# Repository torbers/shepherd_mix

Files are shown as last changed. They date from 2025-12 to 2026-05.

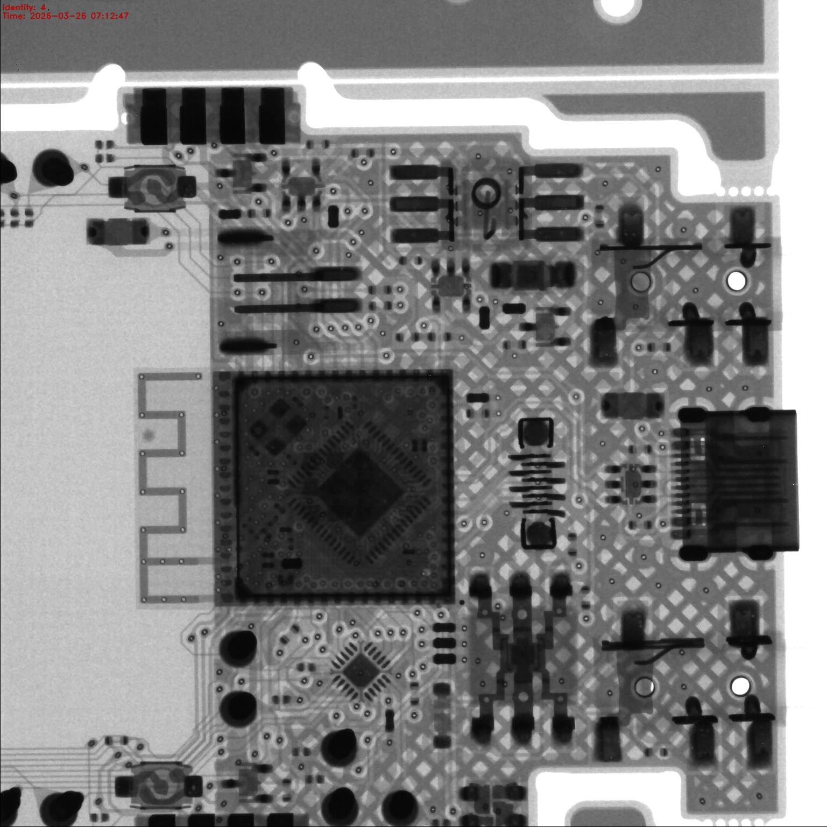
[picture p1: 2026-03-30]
brand/xray/4.jpg

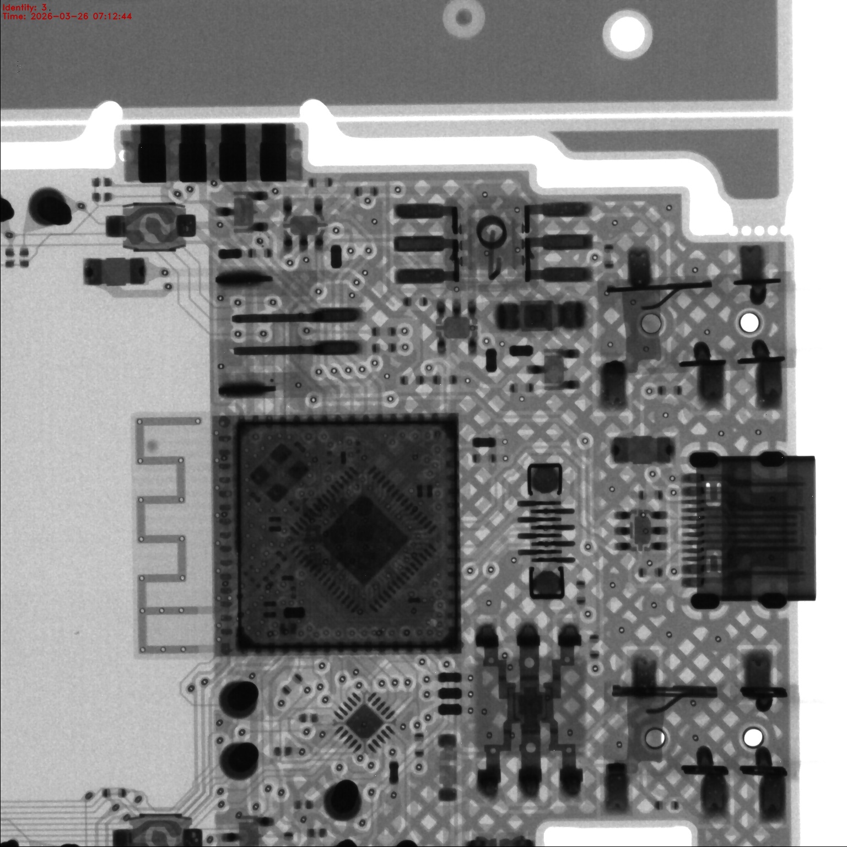
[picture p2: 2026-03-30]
brand/xray/3.jpg

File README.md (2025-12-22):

# shepherd_mix
modular music hardware system for everyone

---

License:

<a href="https://github.com/torbers/shepherd_mix">Shepherd Mix design specifications</a> © 2025 by <a href="http://sambkothe.com">Sam Kothe (torbers)</a> are licensed under <a href="https://creativecommons.org/licenses/by-sa/4.0/">CC BY-SA 4.0</a>

<a href="https://github.com/torbers/shepherd_mix">Shepherd Mix code</a> © 2025 by <a href="http://sambkothe.com">Sam Kothe (torbers)</a> is licensed under <a href="https://creativecommons.org/licenses/by-sa/4.0/">CC BY-SA 4.0</a>

<a href="https://github.com/torbers/shepherd_mix">Shepherd Mix PCB designs</a> © 2025 by <a href="http://sambkothe.com">Sam Kothe (torbers)</a> are licensed under <a href="https://creativecommons.org/licenses/by-nc-sa/4.0/">CC BY-NC-SA 4.0</a>

<a href="https://github.com/torbers/shepherd_mix">Shepherd Mix art</a> © 2025 by <a href="http://sambkothe.com">Sam Kothe (torbers)</a> is licensed under <a href="https://creativecommons.org/licenses/by-nc-sa/4.0/">CC BY-NC-SA 4.0</a>

This means that you may design, manufacture, and sell products compatible with Shepherd Mix or using its code in accordance with [open source standards](https://opensource.org/osd), but you may not sell my PCB source files, artistic designs, or products made with them. In any case, you must give [appropriate credit](https://creativecommons.org/licenses/by-sa/4.0/#ref-appropriate-credit).

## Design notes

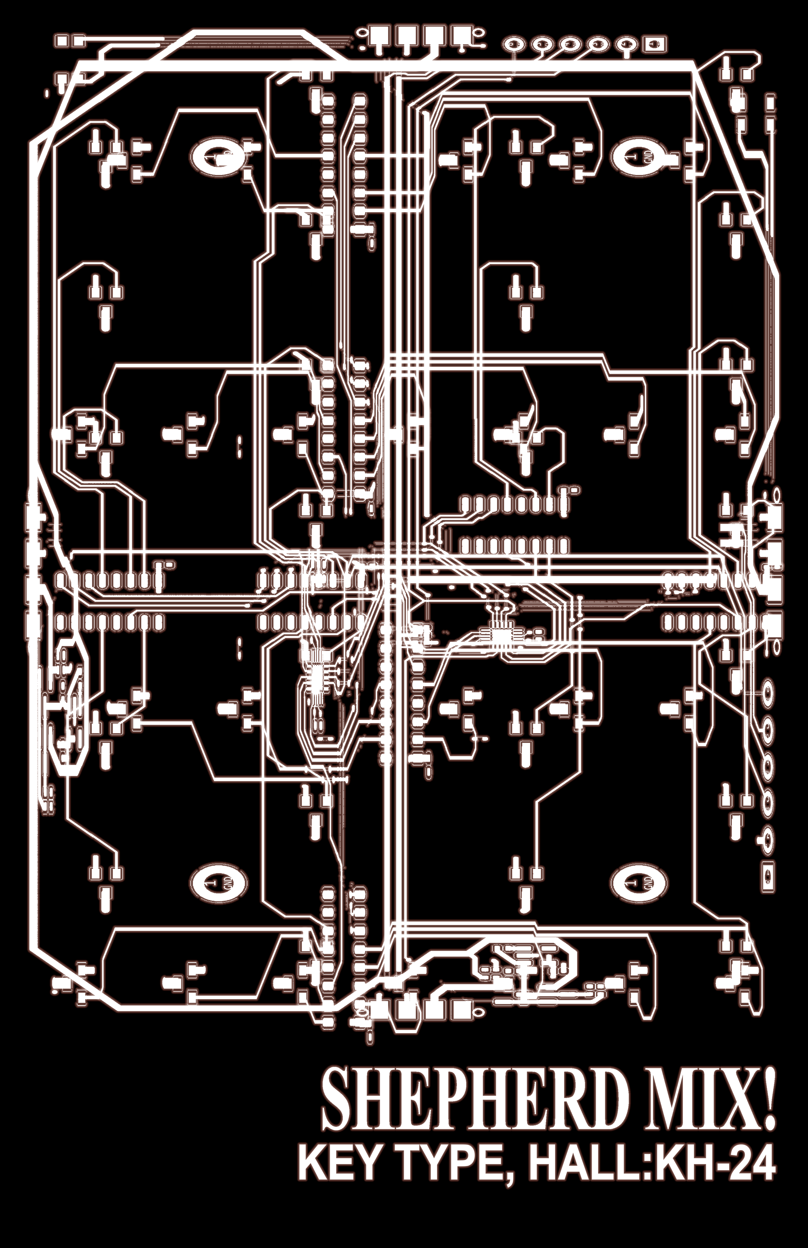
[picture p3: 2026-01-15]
brand/kh-24eva1117_v_both.png

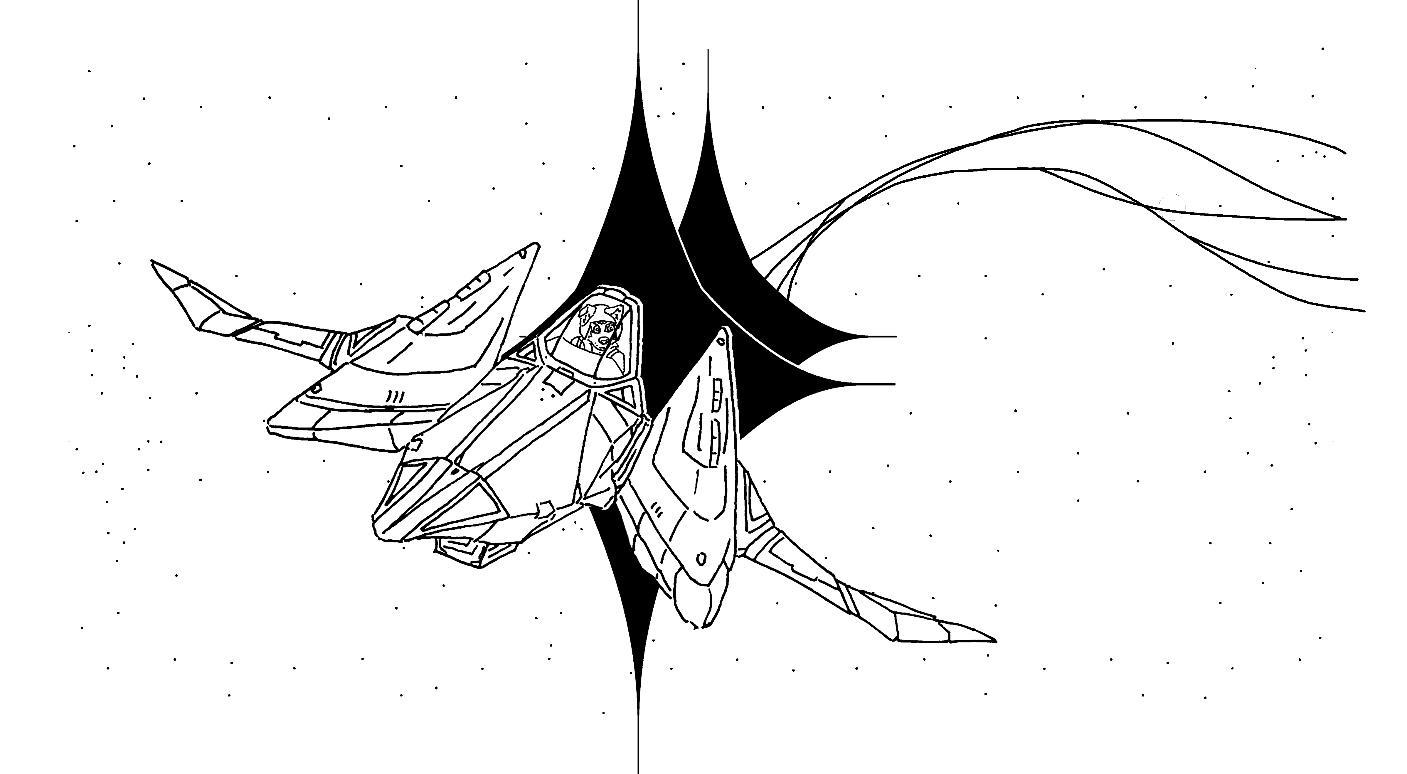
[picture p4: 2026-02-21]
kh-24 hall/hall_main_front3.png

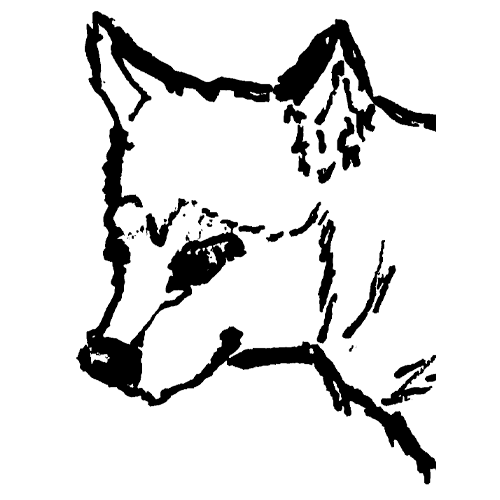
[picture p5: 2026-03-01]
kt-05 ctrl/dog1head.png

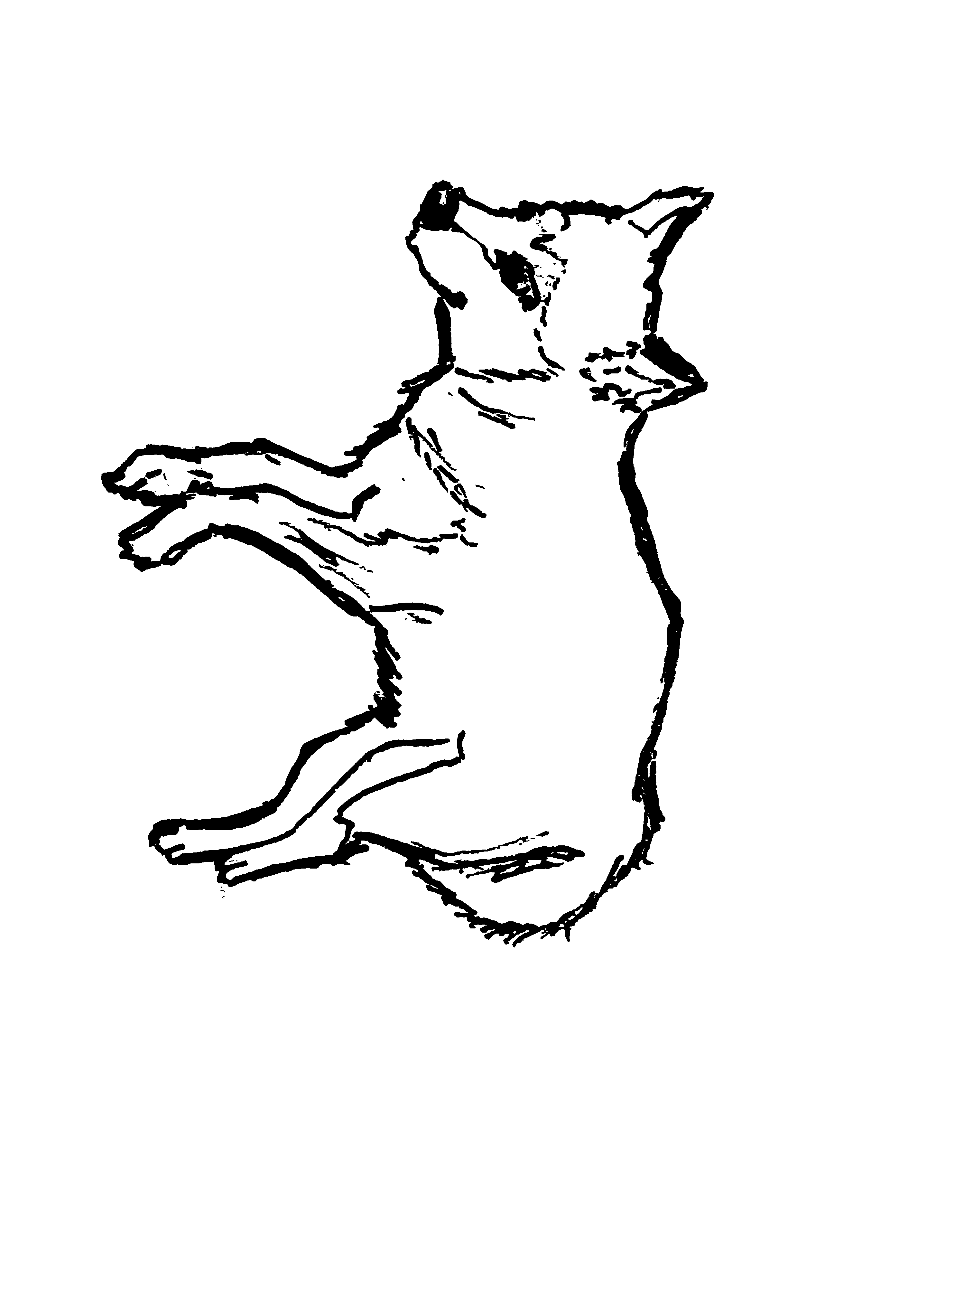
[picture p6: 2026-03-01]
kt-05 ctrl/dog1.png

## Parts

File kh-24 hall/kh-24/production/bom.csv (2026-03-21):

Designator | Footprint | Quantity | Value | LCSC Part #
C1, C2, C3, C4, C5 | 0402 | 5 | 0.1u
C6, C7, C8 | 0402 | 3 | 1u
CN3 | CONN-SMD_YZ199315035T-04025-01 | 1 | Pogo Pin Receptor Right | C5296825
KEY1, KEY10, KEY11, KEY12, KEY13, KEY14, KEY15, KEY16, KEY17, KEY18, KEY19, KEY2, KEY20, KEY21, KEY22, KEY23, KEY24, KEY3, KEY4, KEY5, KEY6, KEY7, KEY8, KEY9 | hall_key_footprint | 24 | 28115181DM | C47121944
LED2 | LED-SMD_4P-L3.2-W2.8_SK6812MINI-EA | 1 | SK6812MINI-EA | C5378731
Q1, Q3 | SOT-23 | 2 | AO3401A
R1, R2, R3, R4, R5, R6, R7, R8, R9 | 0402 | 9 | 10K
U1, U10, U12, U13, U14, U15, U16, U17, U19, U20, U21, U24, U25, U27, U28, U29, U30, U31, U32, U33, U35, U4, U6, U9 | SLSS49E_Hall_Switch_MX | 24 | SLSS49E-3 | C2904393
U11, U5 | DFN1006-2L-BI | 2 | H3V3U10B | C20615782
U18, U26, U3, U34 | SOIC-16_L9.9-W3.9-P1.27-LS6.0-BL | 4 | CD4051BM96 | C21379
U2 | VQFN-20-1EP_3x3mm_P0.4mm_EP1.7x1.7mm | 1 | ATtiny1616-M
U22 | SOT-583-8_L2.1-W1.2-P0.50-LS1.6-BL | 1 | LM66200DRLR | C3235556
U7 | CONN-SMD_4P-L11.0-W5.5-P2.50_YZ165615055F-04025-01 | 1 | Pogo Pin Left | C5296819
U8 | SOT-23-5 | 1 | AP2112K-3.3

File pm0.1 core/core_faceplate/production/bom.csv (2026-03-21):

Designator | Footprint | Quantity | Value | LCSC Part #
CN1, CN15, CN16, CN17, CN18, CN19, CN2, CN20, CN21, CN22, CN4 | SMD-1_BD2.0-H10.0 | 11 | YTC1P-6030-01 | C5221285

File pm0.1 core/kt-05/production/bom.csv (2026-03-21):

Designator | Footprint | Quantity | Value | LCSC Part #
C1, C2, C4, C8, C9 | 0402 | 5 | 10u
C3 | 0402 | 1 | 0.1u
C5, C6, C7 | 0402 | 3 | 1u
CN10, CN11, CN12, CN13, CN14, CN3, CN5, CN6, CN7, CN8, CN9 | SMD-1_BD2.0-H10.0 | 11 | YTC1P-6030-01 | C5221285
CN15 | AUDIO-SMD_PJ-327A5JJ | 1 | MIDI IN | C668605
CN16 | AUDIO-SMD_PJ-327A5JJ | 1 | MIDI OUT | C668605
CN4 | CONN-SMD_YZ199315035T-04025-01 | 1 | Pogo Pin Receptor Right | C5296825
D1 | SOT-23-6_L2.9-W1.6-P0.95-LS2.8-BL | 1 | USBLC6-2SC6 | C7519
D2 | SMA_L4.3-W2.6-LS5.2-RD | 1 | SS34_C8678 | C8678
D3 | D_SOD-123 | 1 | 1N4148W
F1, F2 | F1206 | 2 | BSMD1206-200-6V | C883134
FPC1 | FPC-SMD_8P-P0.50_HDGC_0.5K-A-8PB | 1 | 0.5K-A-8PB | C2914134
H2 | CONN-SMD_2P-P2.00_XUNPU_WAFER-PH2.0-2PWB | 1 | WAFER-PH2.0-2PWB | C3029440
Q1, Q2, Q3 | SOT-23 | 3 | AO3401A
R1, R20, R3 | 0402 | 3 | 5.1k
R10, R11, R2, R24, R4, R6, R7, R8, R9 | 0402 | 9 | 10K
R21, R22, R23 | 0402 | 3 | 100K
R25 | 0402 | 1 | 1M
R26 | 0402 | 1 | 10
R27 | 0402 | 1 | 33
R28, R29 | 0402 | 2 | 470
R5 | 0402 | 1 | 22R
SW1 | SW-SMD_L3.9-W3.0-P4.45 | 1 | ESP RST | C720477
SW2 | SW-SMD_L3.9-W3.0-P4.45 | 1 | ESP BOOT | C720477
U1 | LED-SMD_4P-L3.5-W3.5-BR_SK6812MINI-HS | 1 | SK6812MINI-HS | C2922787
U10, U11, U12, U13, U14, U15, U16, U17, U18, U19, U20, U21, U22, U23, U7 | DFN1006-2L-BI | 15 | H3V3U10B | C20615782
U2 | SOT-23-5 | 1 | AP2112K-3.3
U3 | SOT-23-5 | 1 | MCP73831-2-OT
U4 | SW-SMD_6P-L5.8-W5.8-P2.00-LS11.3 | 1 | PS-5850SVB-6PL | C5155567
U5 | SMD-6_L7.3-W6.5-P2.54-LS10.2-BL | 1 | H11L1S(TA) | C78589
U6 | VQFN-20-1EP_3x3mm_P0.4mm_EP1.7x1.7mm | 1 | ATtiny1616-M
U8 | ESP32-S2-MINI-1 | 1 | ESP32-S3-MINI-1
U9 | CONN-SMD_4P-L11.0-W5.5-P2.50_YZ165615055F-04025-01 | 1 | Pogo Pin Left | C5296819
USBC1 | USB-C_SMD-TYPE-C-31-M-12_1 | 1 | TYPE-C-31-M-12 | C165948

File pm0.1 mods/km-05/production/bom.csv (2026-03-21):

Designator | Footprint | Quantity | Value | LCSC Part #
C1 | 0402 | 1 | 0.1u
C6, C7 | 0402 | 2 | 10u
C8 | 0402 | 1 | 1u
CN1, CN10, CN11, CN12, CN14, CN2, CN4, CN5, CN6, CN7, CN8, CN9 | SMD-1_BD2.0-H10.0 | 12 | YTC1P-6030-01 | C5221285
CN3 | CONN-SMD_YZ199315035T-04025-01 | 1 | Pogo Pin Receptor Right | C5296825
Q3, Q4 | SOT-23 | 2 | AO3401A
R1, R2, R29, R3, R4 | 0402 | 5 | 10K
R10, R11, R12, R13, R14, R15, R16, R17, R18, R19, R20, R9 | 0402 | 12 | 0R
U1, U19, U20, U21, U22, U23, U24, U25 | LED-SMD_4P-L3.5-W3.5-BR_SK6812MINI-HS | 8 | SK6812MINI-HS | C2922787
U10, U11, U12, U13, U14, U15, U16, U17, U18, U3, U4, U5, U6, U9 | DFN1006-2L-BI | 14 | H3V3U10B | C20615782
U2 | VQFN-20-1EP_3x3mm_P0.4mm_EP1.7x1.7mm | 1 | ATtiny1616-M
U26 | SOT-583-8_L2.1-W1.2-P0.50-LS1.6-BL | 1 | LM66200DRLR | C3235556
U7 | CONN-SMD_4P-L11.0-W5.5-P2.50_YZ165615055F-04025-01 | 1 | Pogo Pin Left | C5296819
U8 | SOT-23-5 | 1 | AP2112K-3.3

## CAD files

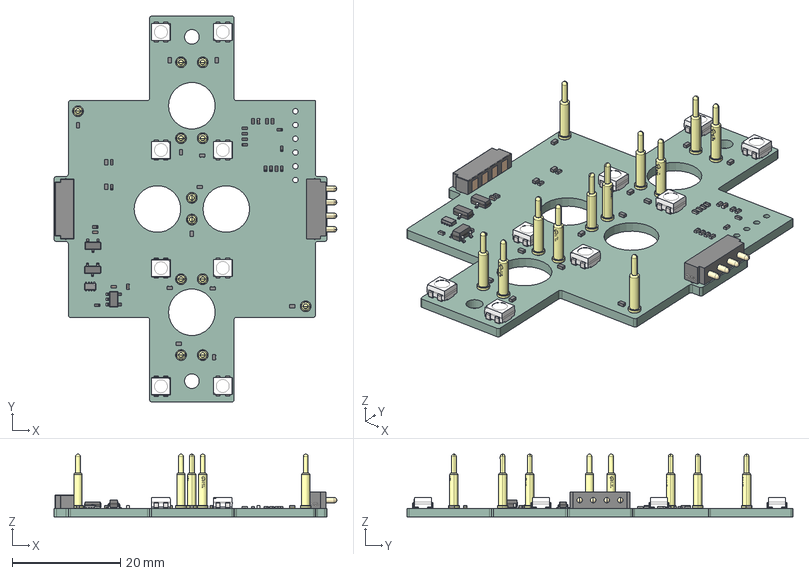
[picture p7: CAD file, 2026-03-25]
3d/complex/mods.step
52.1 x 71.2 x 11.6 mm
SMD-1_BD2.0-H10.0 x 12
R_0402_1005Metric x 17
LED-SMD_4P-L3.5-W3.5-BR_SK6812MINI-HS x 8
DFN1006-2L-BI x 14
SOT-23 x 2
CONN-SMD_YZ199315035T-04025-01
SOT-583-8_L2.1-W1.2-P0.50-LS1.6-BL
SOT-23-5
CONN-SMD_4P-L11.0-W5.5-P2.50_YZ165615055F-04025-01
C_0402_1005Metric x 4
km-05_PCB

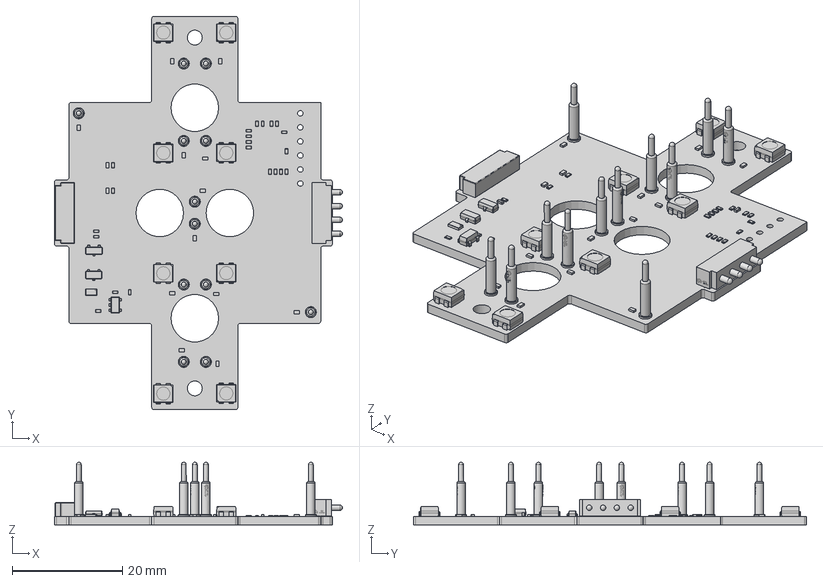
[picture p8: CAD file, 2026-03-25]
3d/MODS.step
52.1 x 71.2 x 11.3 mm

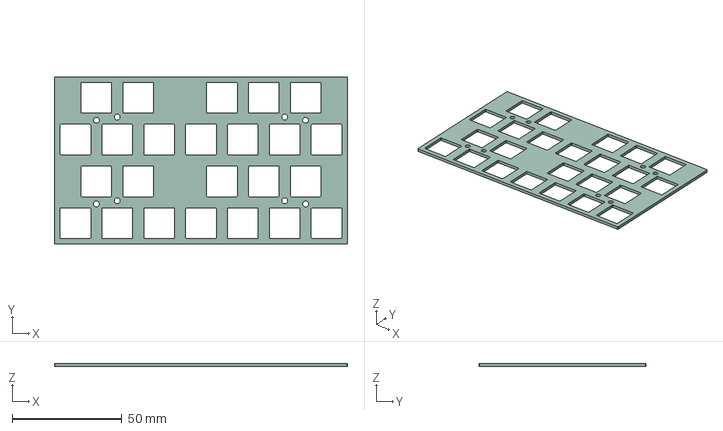
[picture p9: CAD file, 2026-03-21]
kh-24 hall/hall face/hall face.step
133.3 x 76.2 x 1.51 mm

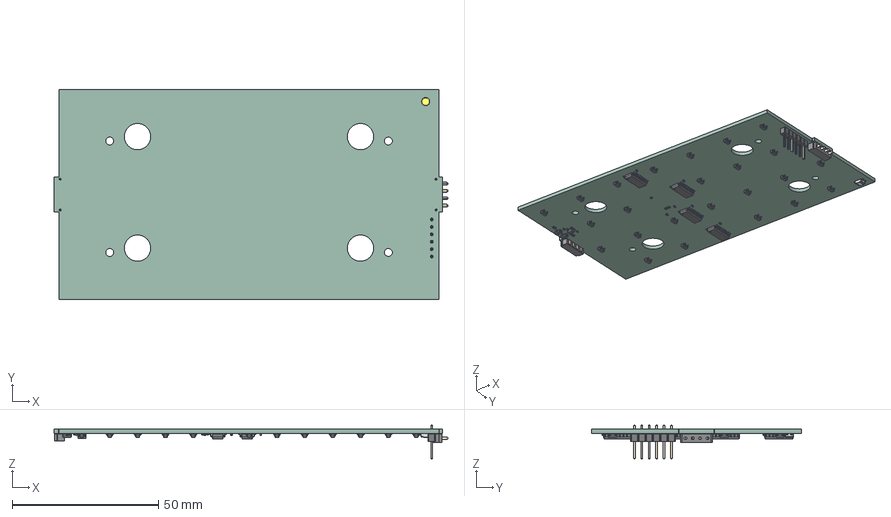
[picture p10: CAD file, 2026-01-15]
kh-24 hall/kh-24/kh-24.step
134.7 x 71.8 x 11.5 mm
C_0402_1005Metric x 7
SOT-23-3 x 24
SOIC-16_3.9x9.9mm_P1.27mm x 4
CONN-SMD_4P-L11.0-W5.5-P2.50_YZ165615055F-04025-01
SOT-23 x 2
R_0402_1005Metric x 8
DFN1006-2L-BI x 2
CONN-SMD_YZ199315035T-04025-01
PinHeader_1x06_P2.54mm_Vertical
LED-SMD_4P-L3.2-W2.8_SK6812MINI-EA
SOT-23-5
kh-24_PCB

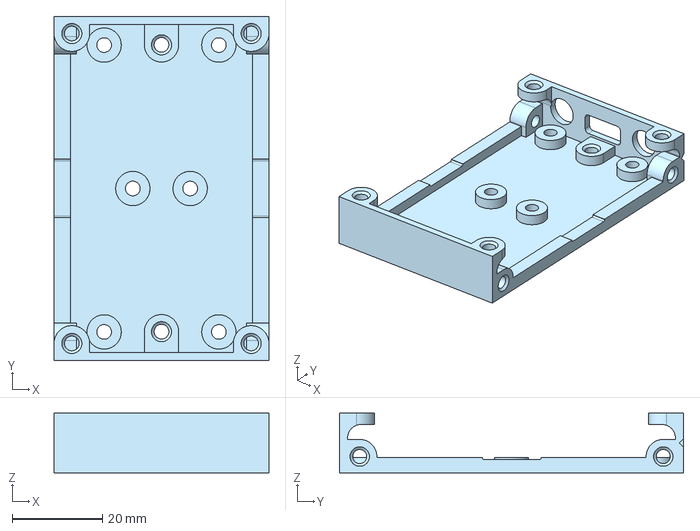
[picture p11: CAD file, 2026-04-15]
pm0.1 core/core - case.step
47.6 x 76.2 x 13.2 mm

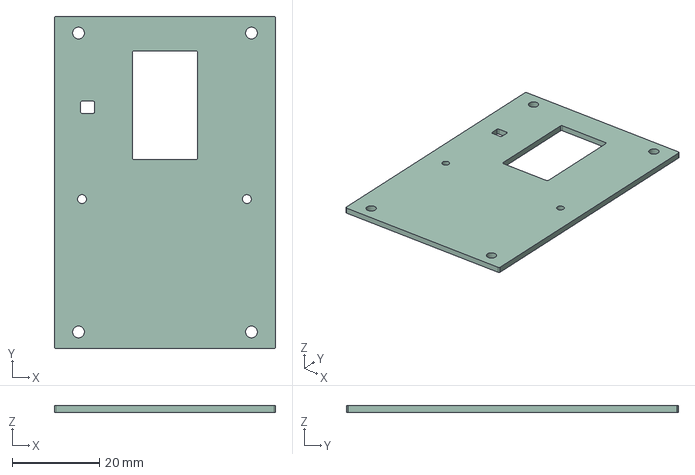
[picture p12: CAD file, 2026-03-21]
pm0.1 core/core_faceplate/core_faceplate.step
50.8 x 76.2 x 1.51 mm

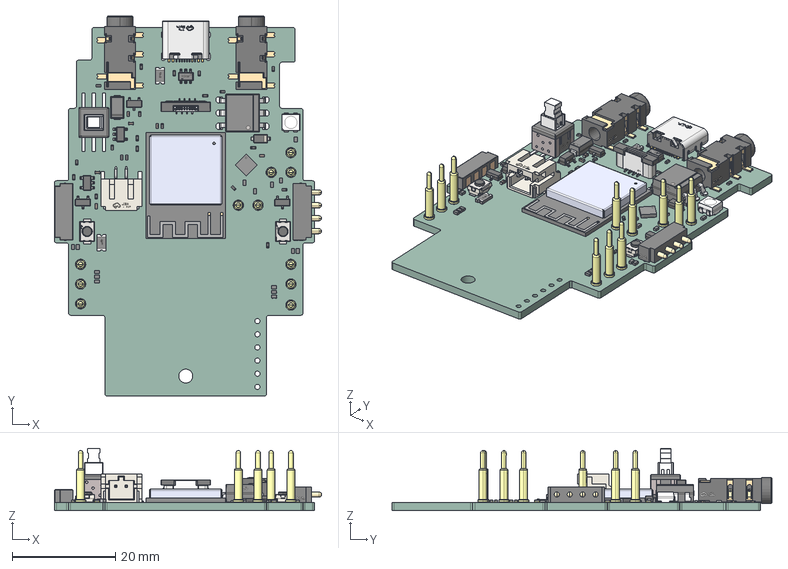
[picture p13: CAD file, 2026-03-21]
pm0.1 core/kt-05/kt-05.step
51.7 x 73.4 x 12.0 mm
R_0402_1005Metric x 21
FPC-SMD_8P-P0.50_HDGC_0.5K-A-8PB
F1206_L3.2-W1.7-H0.6 x 2
DFN1006-2L-BI x 15
SMD-1_BD2.0-H10.0 x 11
CONN-SMD_4P-L11.0-W5.5-P2.50_YZ165615055F-04025-01
C_0402_1005Metric x 6
LED-SMD_4P-L3.5-W3.5-BR_SK6812MINI-HS
CONN-SMD_2P-P2.00_XUNPU_WAFER-PH2.0-2PWB
SW-SMD_L3.9-W2.9-H2.0-LS4.8 x 2
SOT-23 x 3
USB-C_SMD-TYPE-C-31-M-12_1
SOT-23-6_L2.9-W1.6-H1.5-LS2.8-P0.95
AUDIO-SMD_PJ-327A5JJ x 2
QFN-20_L3.0-W3.0-P0.40-BL-EP1.7
ESP32-S2-MINI-1
SOT-23-5 x 2
D_SOD-123
SMA_L4.3-W2.6-LS5.2-RD
SW-SMD_6P-L5.8-W5.8-P2.00-LS11.3
SMD-6_L7.3-W6.5-H3.6-LS10.16-P2.54
CONN-SMD_YZ199315035T-04025-01
kt-05_PCB

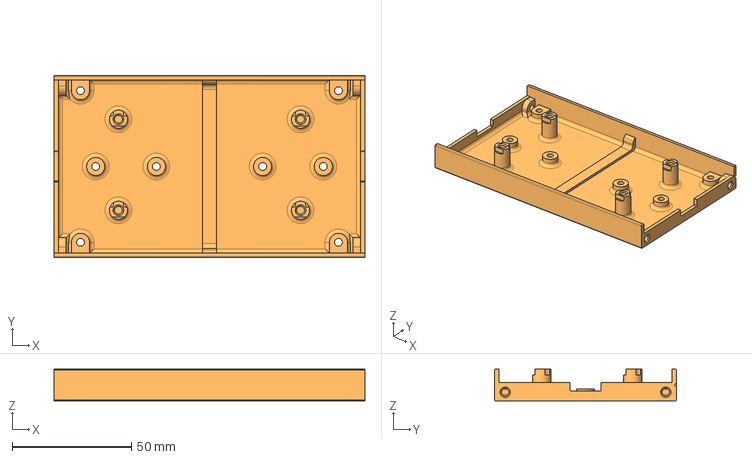
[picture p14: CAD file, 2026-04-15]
pm0.1 hall/hall - case.step
130.2 x 76.2 x 13.2 mm

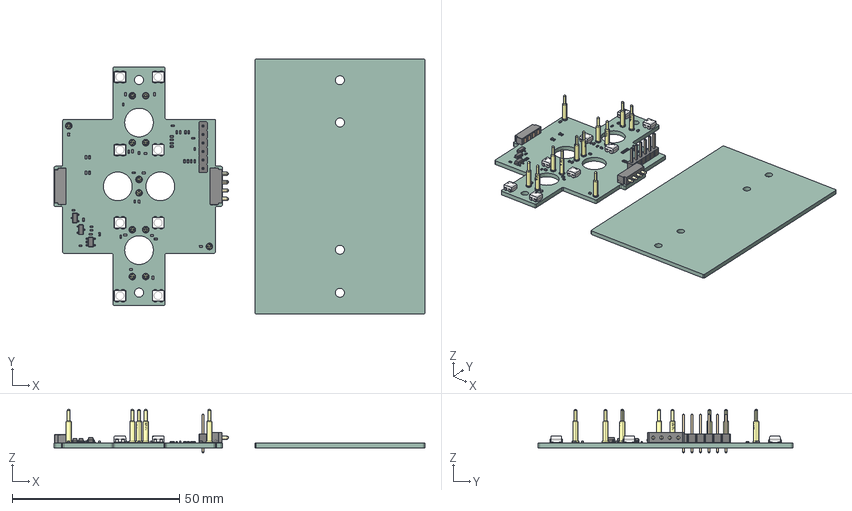
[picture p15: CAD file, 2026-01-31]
pm0.1 mods/km-05/km-05.step
110.8 x 76.2 x 13.0 mm
SMD-1_BD2.0-H10.0 x 12
SOT-23 x 2
LED-SMD_4P-L3.5-W3.5-BR_SK6812MINI-HS x 8
DFN1006-2L-BI x 14
R_0402_1005Metric x 28
CONN-SMD_YZ199315035T-04025-01
SOT-23-5
CONN-SMD_4P-L11.0-W5.5-P2.50_YZ165615055F-04025-01
PinHeader_1x06_P2.54mm_Vertical
C_0402_1005Metric x 3
km-05_PCB_1
km-05_PCB_2

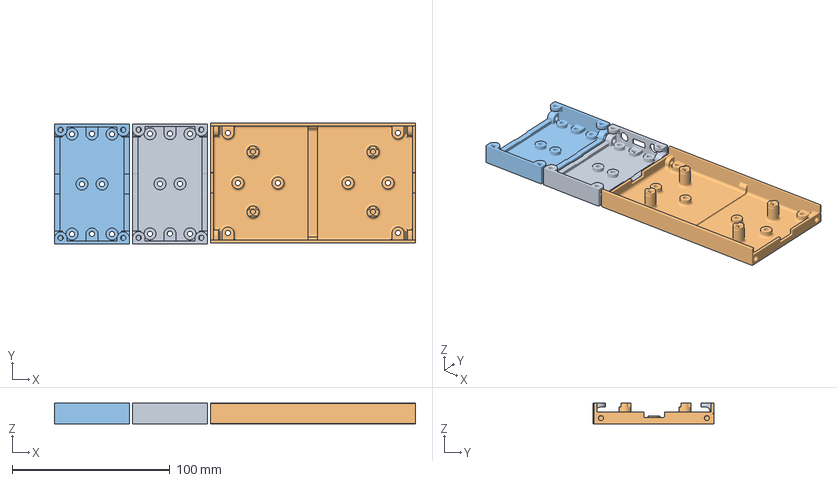
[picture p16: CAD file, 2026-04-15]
smix_all_xl.3mf
229.1 x 76.9 x 13.2 mm
core - case
hall - case
mods - case

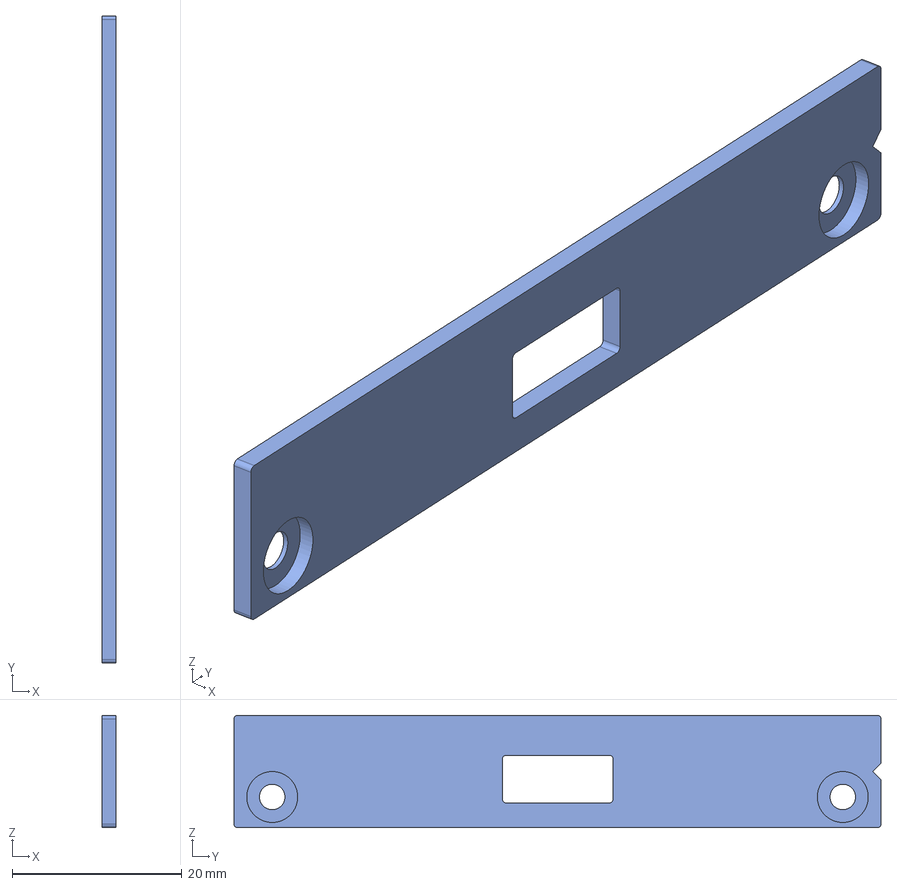
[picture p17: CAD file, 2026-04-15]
step/mods - mods_core_side_r.step
1.60 x 76.2 x 13.2 mm

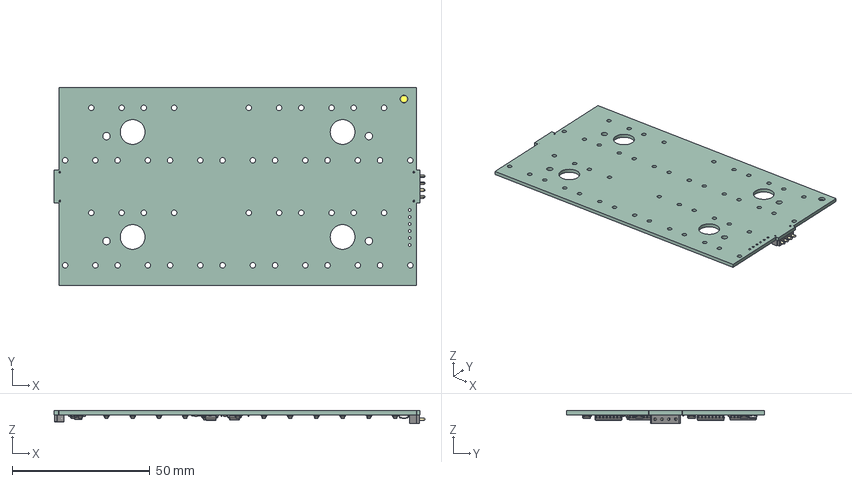
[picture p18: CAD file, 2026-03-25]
3d/complex/hall.step
134.7 x 71.8 x 4.60 mm
SOT-23 x 2
C_0402_1005Metric x 8
R_0402_1005Metric x 9
SOT-23-3 x 24
SOIC-16_3.9x9.9mm_P1.27mm x 2
CONN-SMD_4P-L11.0-W5.5-P2.50_YZ165615055F-04025-01
SOIC-16_L9.9-W3.9-H1.8-LS6.0-P1.27 x 2
DFN1006-2L-BI x 2
CONN-SMD_YZ199315035T-04025-01
SOT-583-8_L2.1-W1.2-P0.50-LS1.6-BL
LED-SMD_4P-L3.2-W2.8_SK6812MINI-EA
SOT-23-5
kh-24_PCB

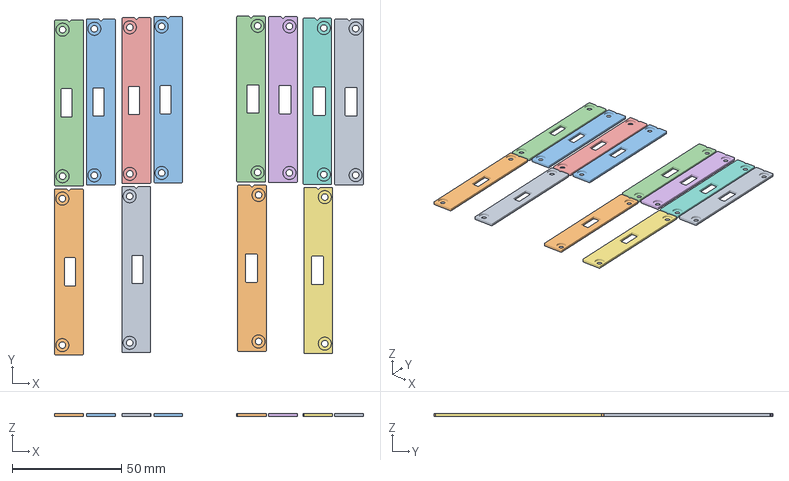
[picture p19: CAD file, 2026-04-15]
step/sides.3mf
141.7 x 155.4 x 1.60 mm
hall - hall_side_l x 2
hall - hall_side_r x 2
mods - mods_core_side_l x 4
mods - mods_core_side_r x 4

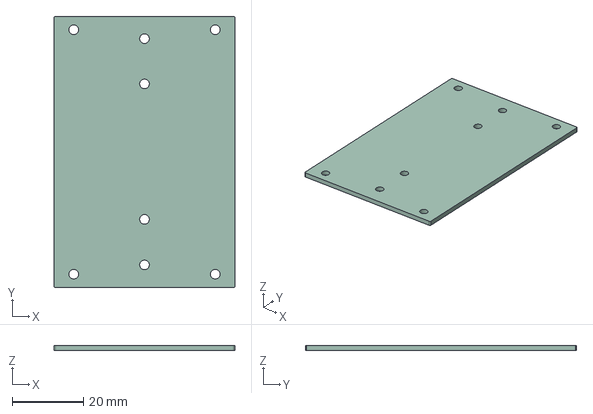
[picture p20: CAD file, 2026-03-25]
3d/mods_faceplate.step
50.8 x 76.2 x 1.51 mm

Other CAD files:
pm0.1 mods/mods - case.step
3d/HALL.step
3d/complex/core.step
step/mods - mods_core_side_l.step
3d/CORE.step
3d/core_faceplate.step
3d/hall_faceplate.step
kh-24 hall/hall face/hall face-F_Silkscreen.dxf
new_old/3d/CORE.step
new_old/3d/HALL.step
new_old/3d/complex/core.step
new_old/3d/core_faceplate.step
new_old/3d/hall_faceplate.step
new_old/kh-24 hall/hall face/hall face-F_Silkscreen.dxf
new_old/step/core - case.step
new_old/step/hall - case.step
new_old/step/hall - hall_side_l.step
new_old/step/hall - hall_side_r.step
new_old/step/mods - case.step
new_old/step/mods_core_side_l.step
new_old/step/mods_core_side_r.step
new_old/step/shep_rebuild.3mf
old/m2/mctl_p_v4 - face.dxf
old/m2/mctl_p_v4 - pcb.dxf
step/core - case.step
step/hall - case.step
step/hall - hall_side_l.step
step/hall - hall_side_r.step
step/mods - case.step
step/mods_core_side_l.step
step/mods_core_side_r.step

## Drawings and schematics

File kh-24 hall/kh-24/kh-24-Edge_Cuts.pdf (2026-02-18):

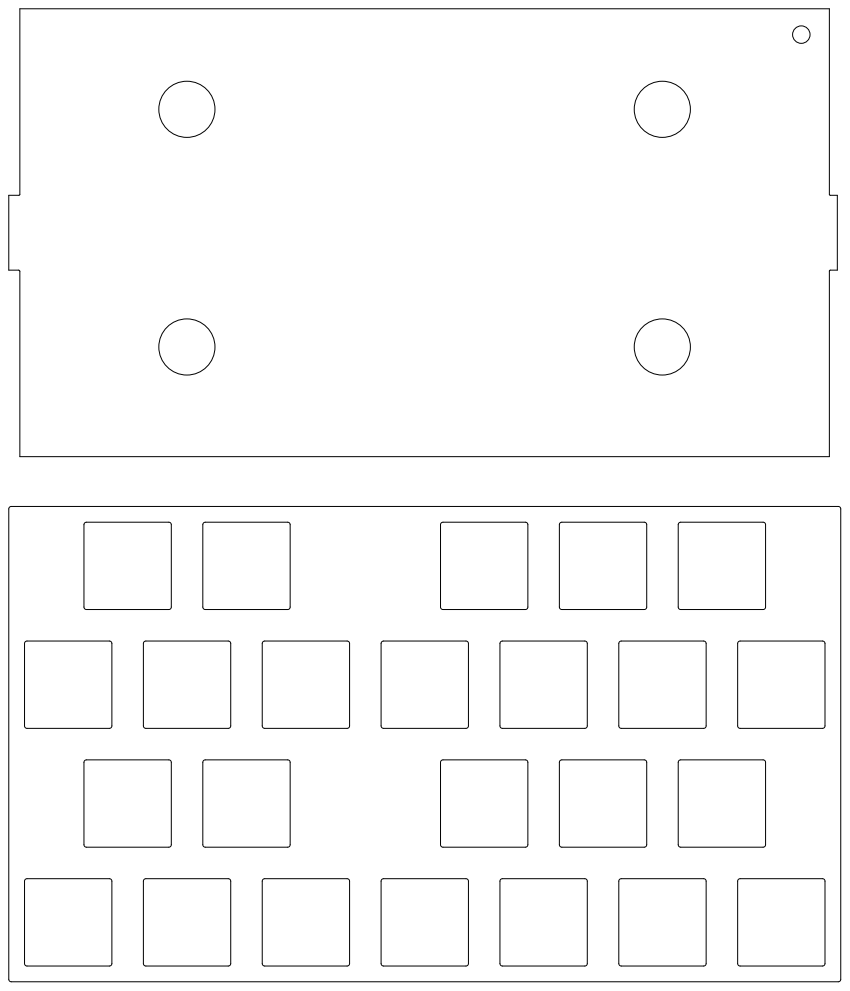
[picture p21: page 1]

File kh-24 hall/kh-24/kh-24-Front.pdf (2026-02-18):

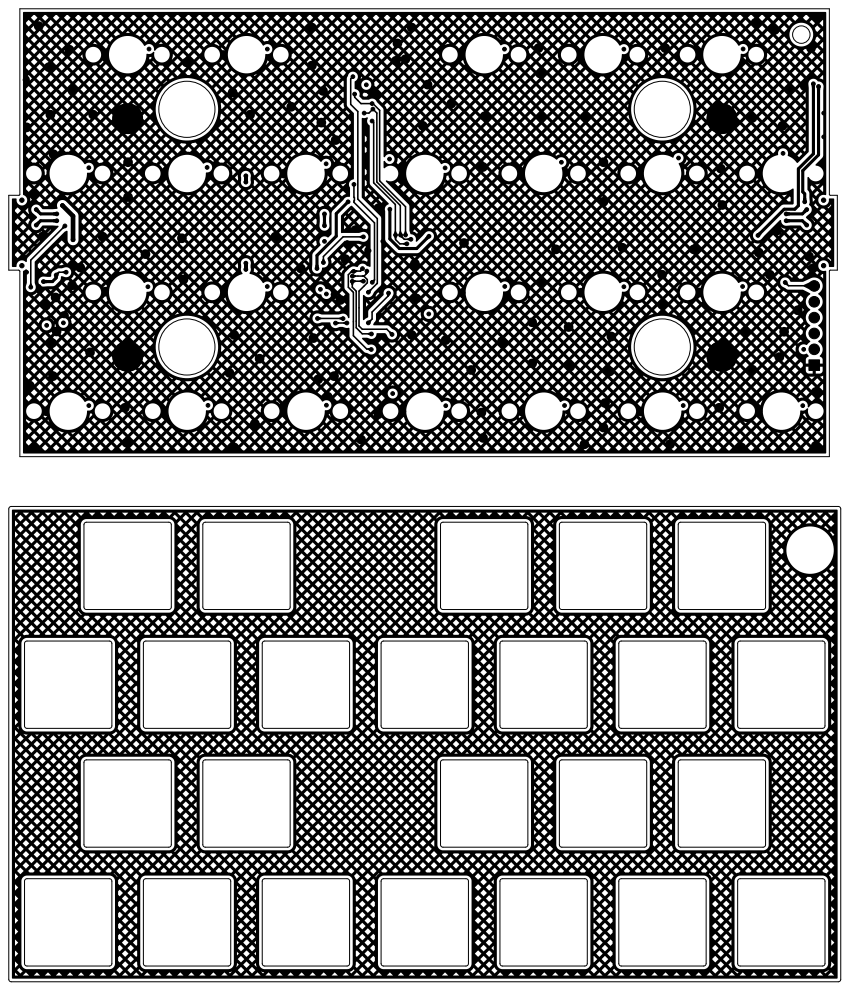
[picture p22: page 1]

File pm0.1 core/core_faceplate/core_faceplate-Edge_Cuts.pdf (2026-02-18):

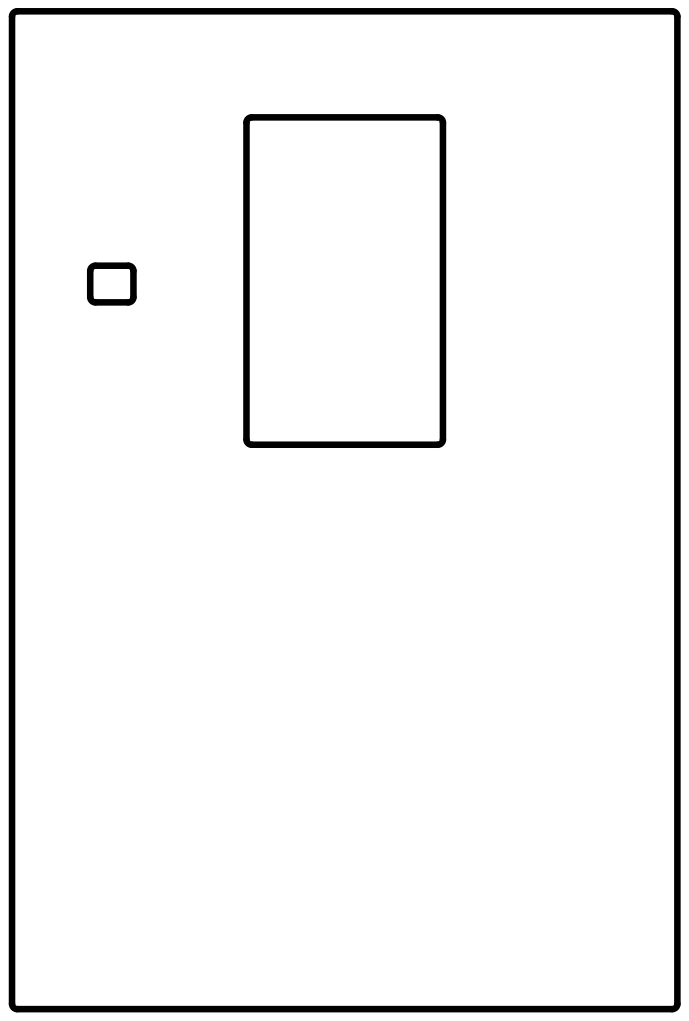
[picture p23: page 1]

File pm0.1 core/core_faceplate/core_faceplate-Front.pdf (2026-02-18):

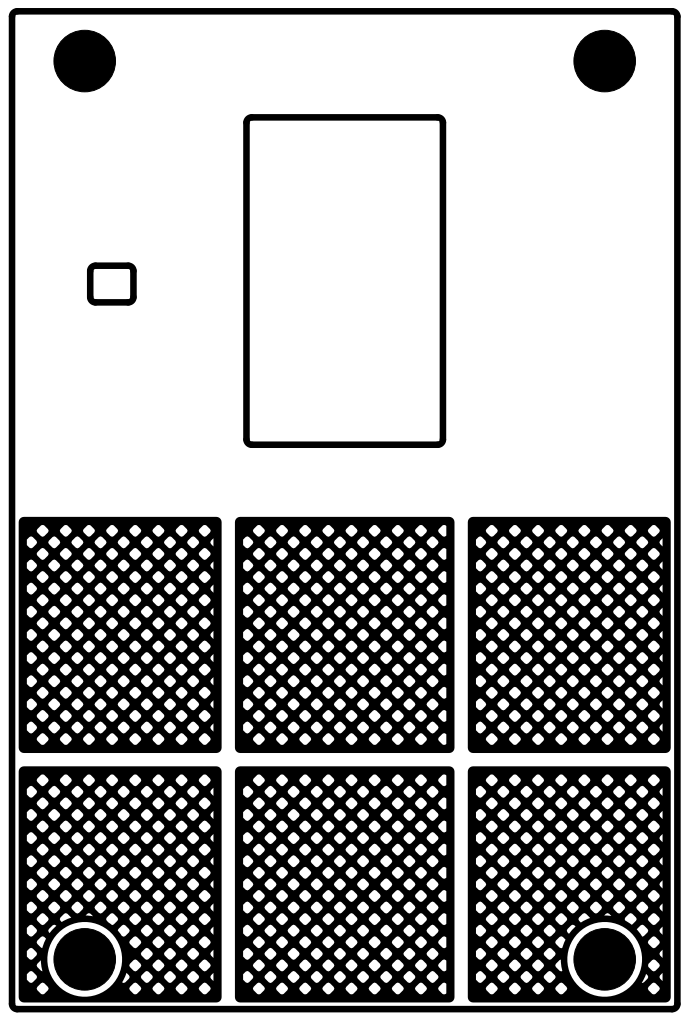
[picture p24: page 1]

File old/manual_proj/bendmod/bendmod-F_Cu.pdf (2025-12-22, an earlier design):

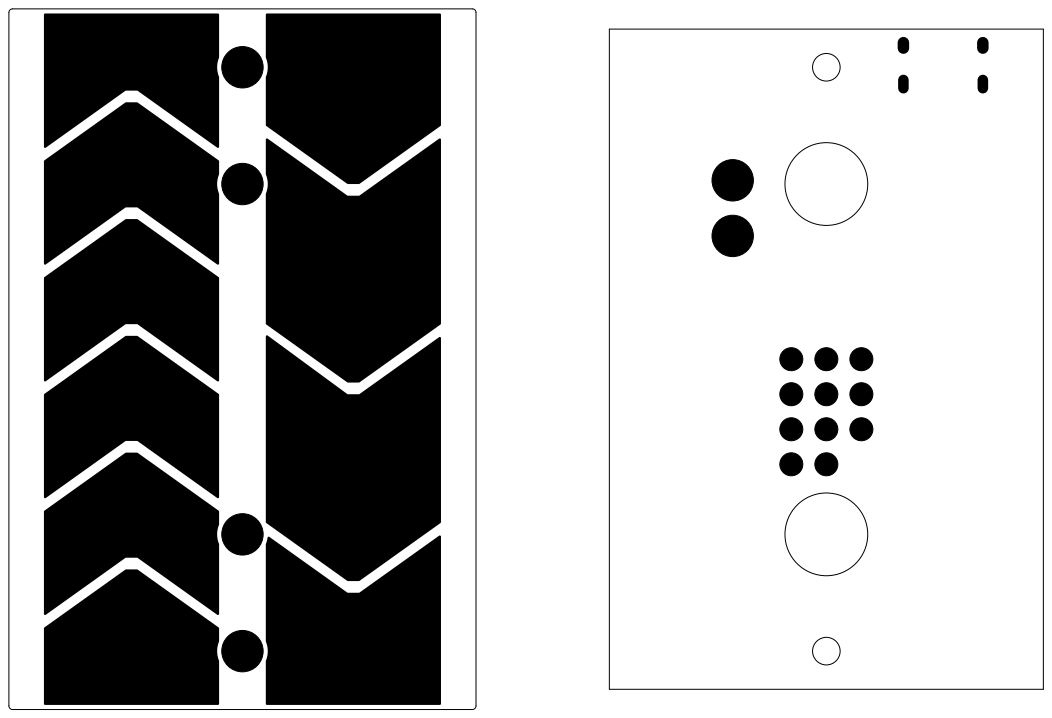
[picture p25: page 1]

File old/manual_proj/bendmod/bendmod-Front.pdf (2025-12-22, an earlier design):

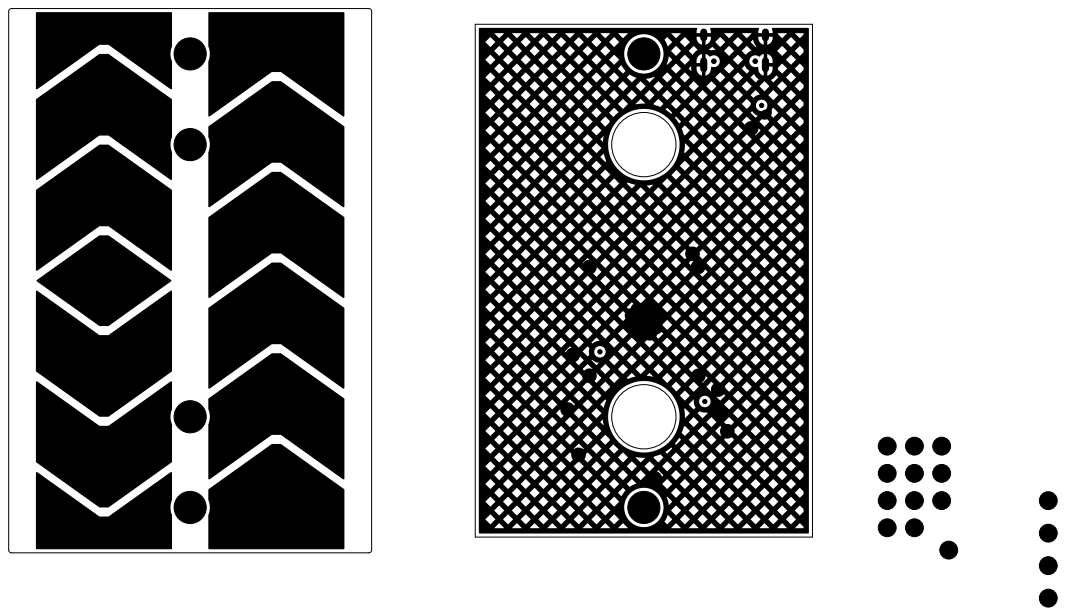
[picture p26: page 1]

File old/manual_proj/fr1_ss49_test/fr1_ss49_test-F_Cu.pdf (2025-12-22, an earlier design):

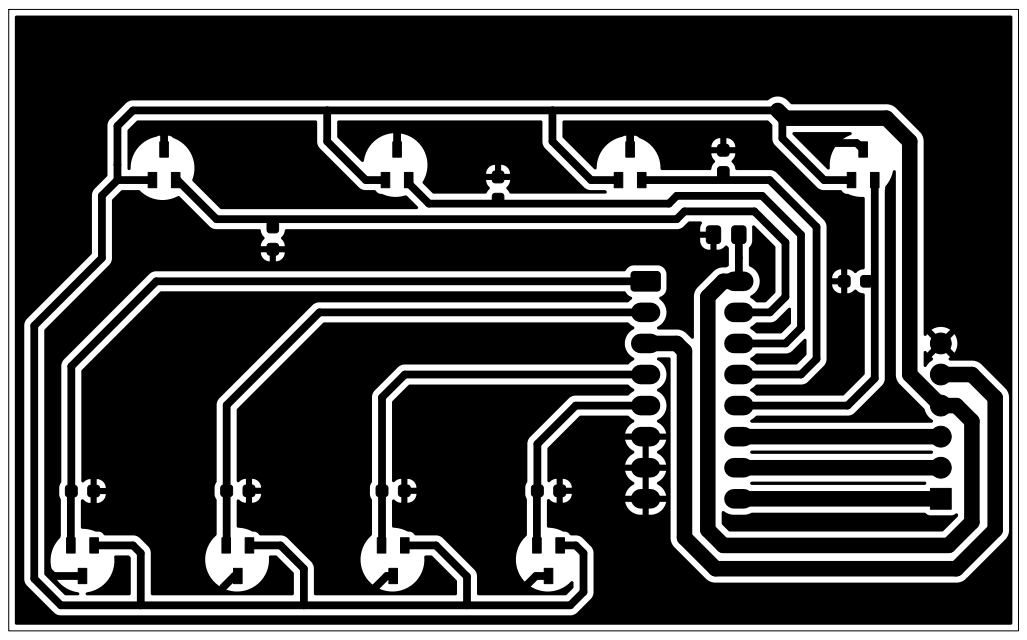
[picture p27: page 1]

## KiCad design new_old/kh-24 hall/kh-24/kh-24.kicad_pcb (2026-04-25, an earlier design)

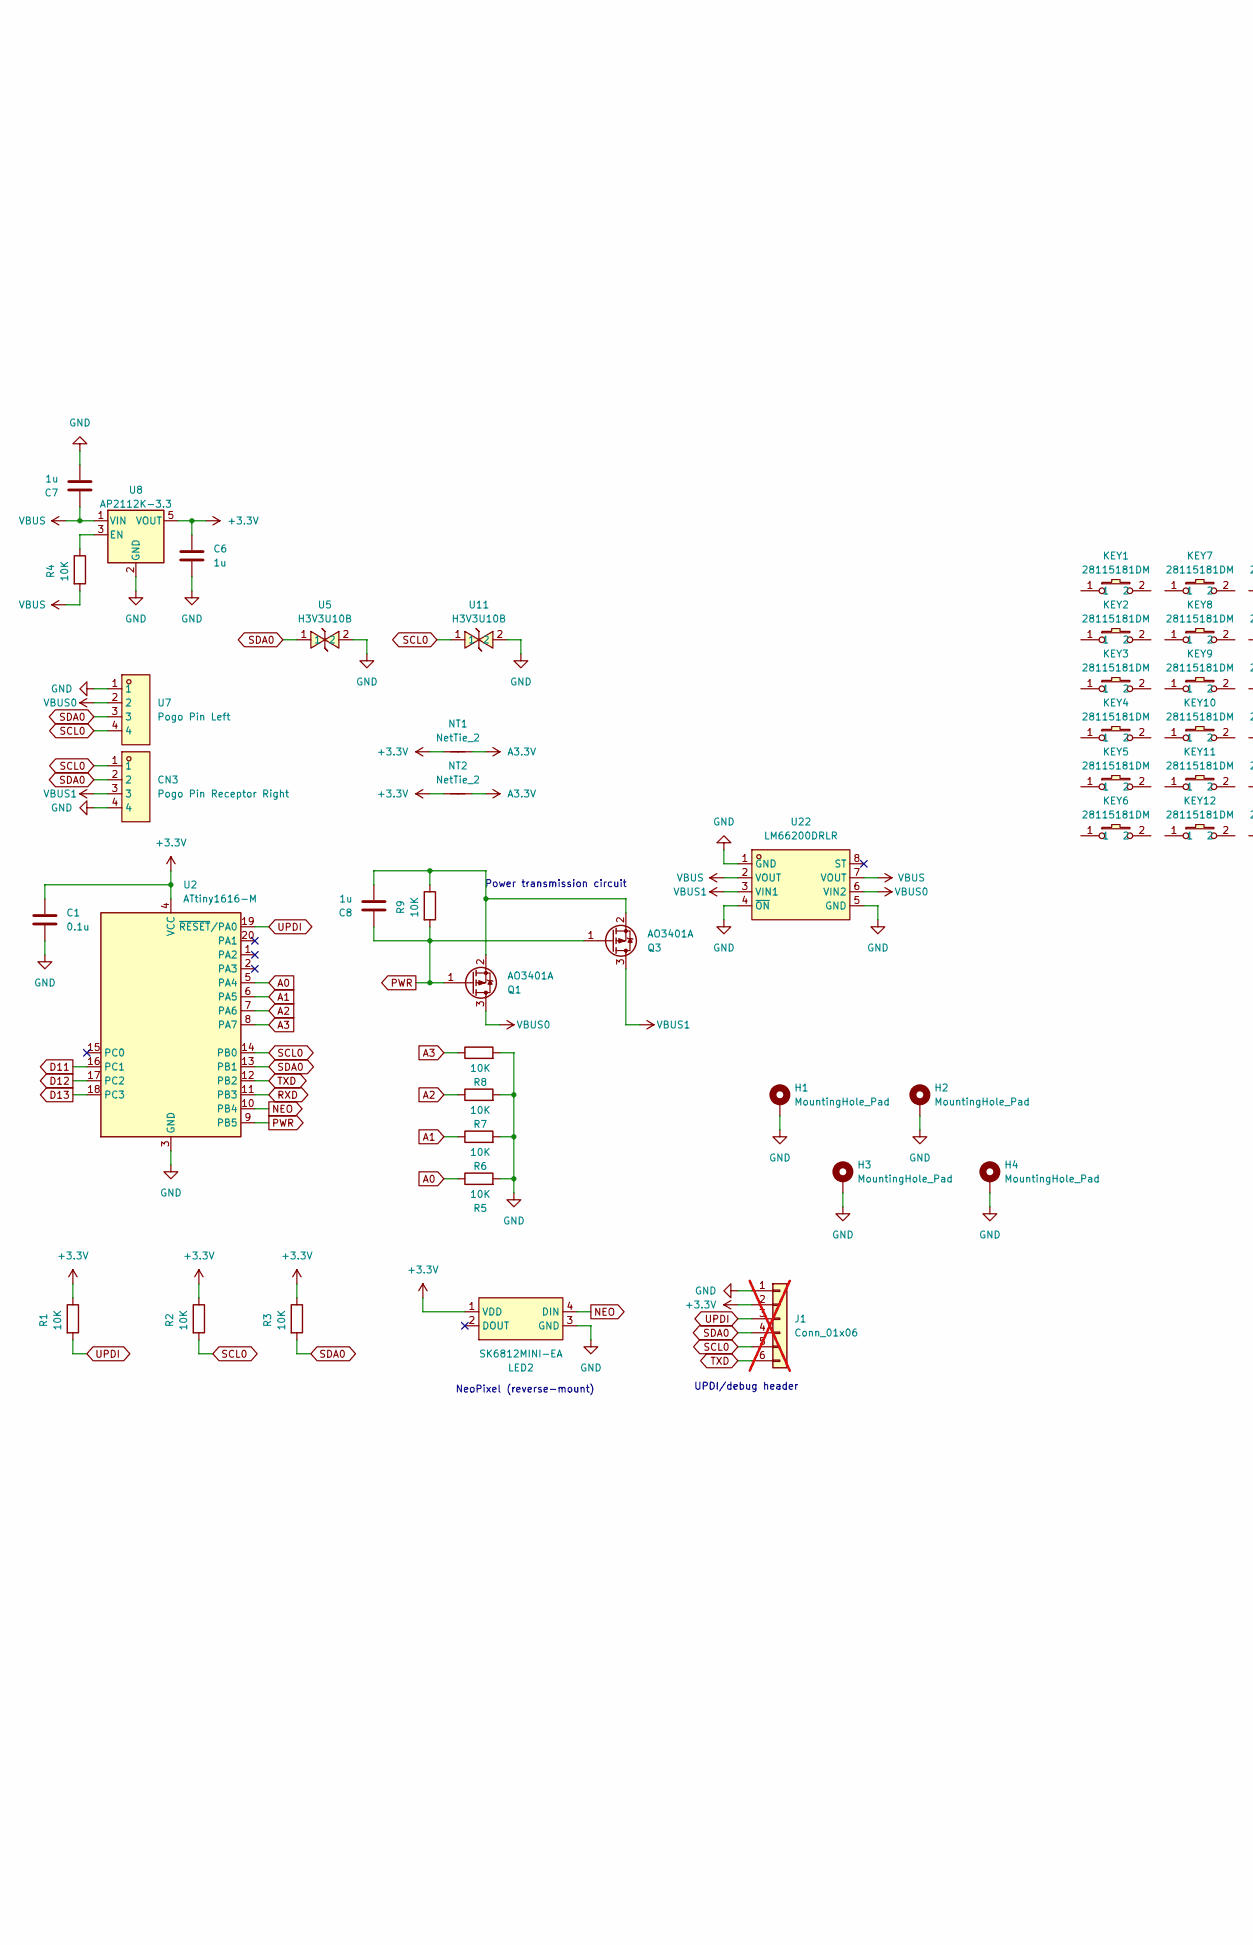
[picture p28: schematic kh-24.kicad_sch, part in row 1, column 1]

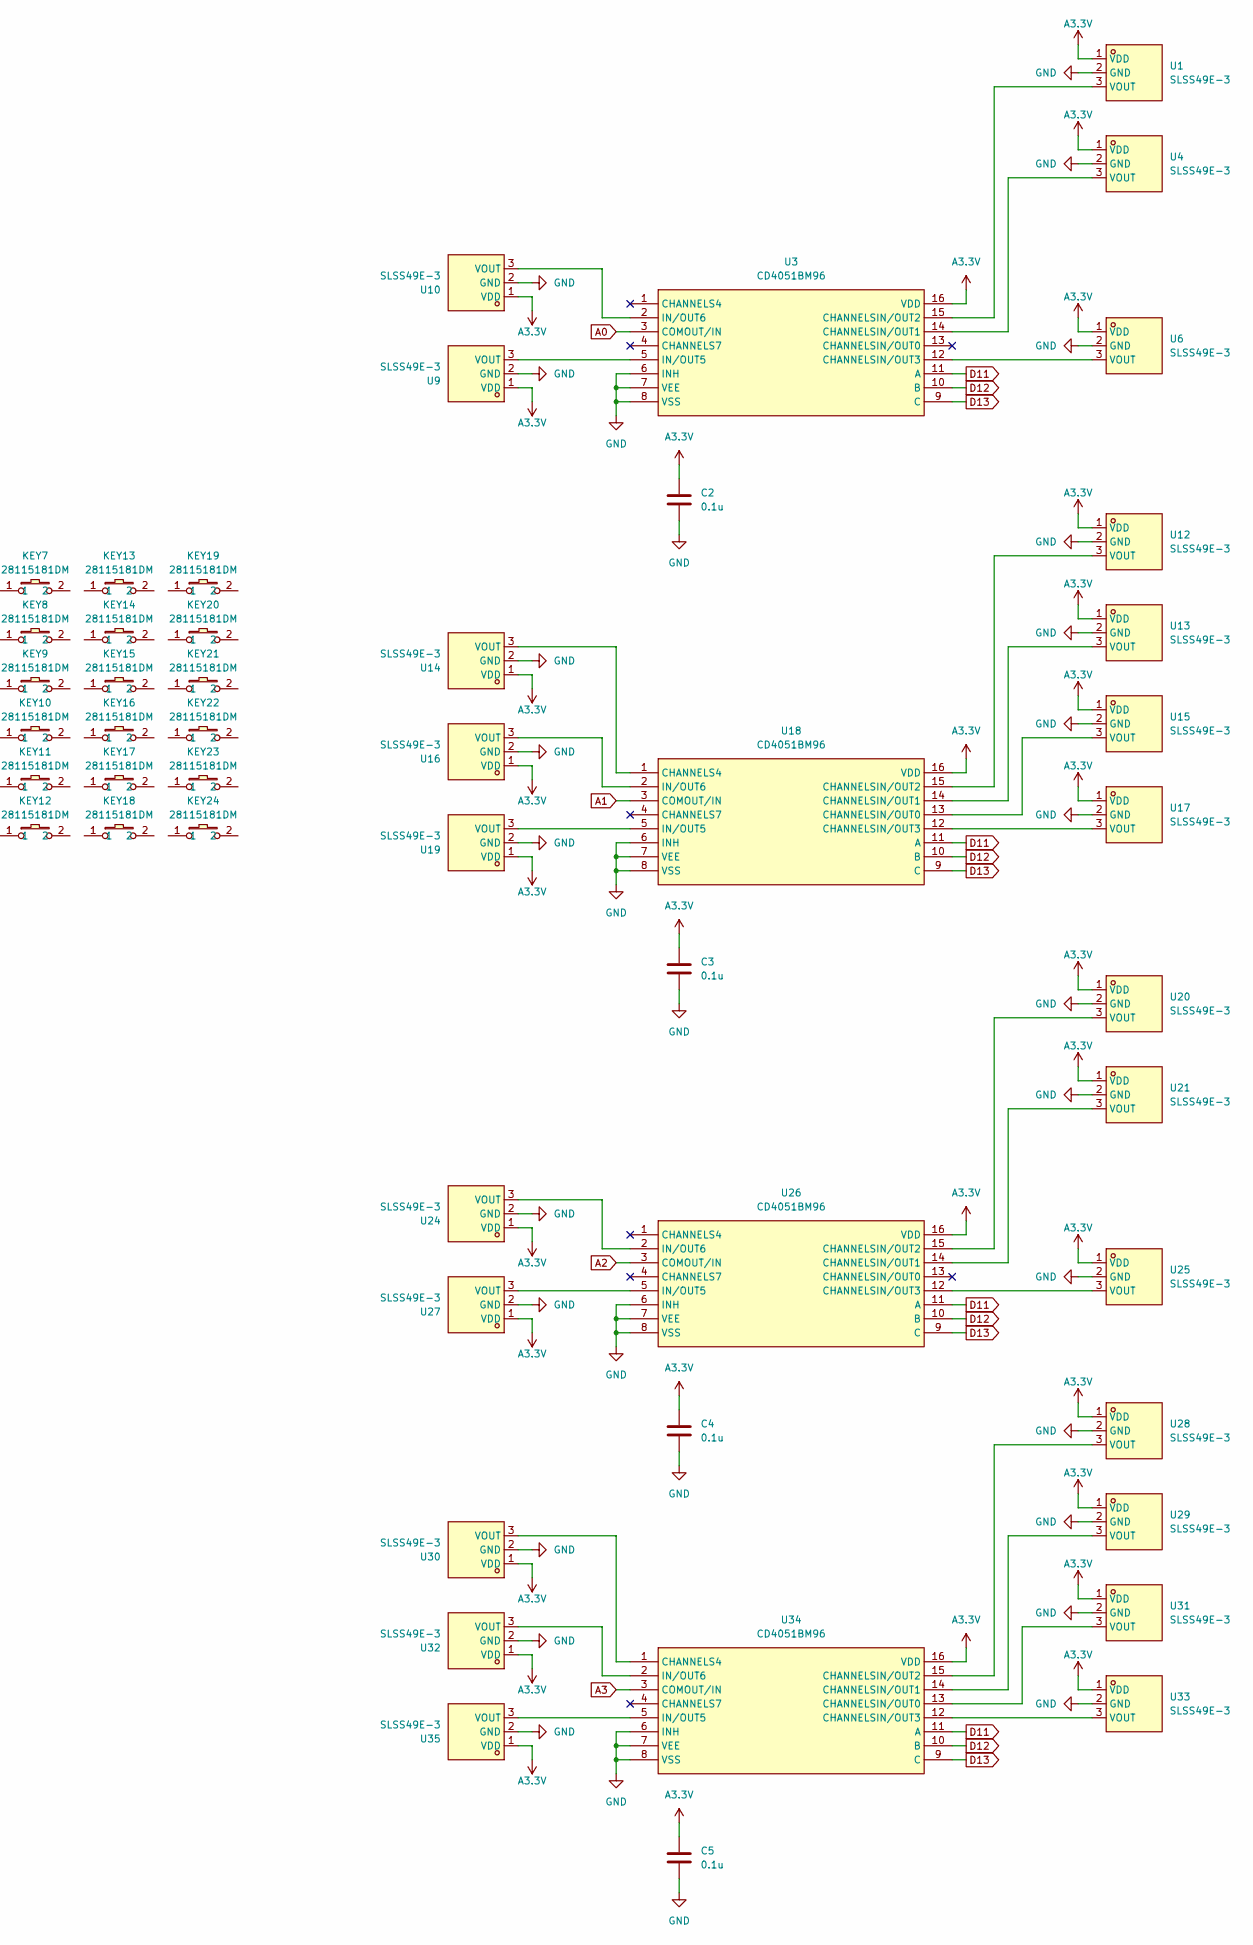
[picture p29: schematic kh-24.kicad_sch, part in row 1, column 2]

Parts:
C1, C2, C3, C4, C5: 0.1u; C_0402_1005Metric
C6, C7, C8: 1u; C_0402_1005Metric
CN3: Pogo Pin Receptor Right; CONN-SMD_YZ199315035T-04025-01; LCSC Part C5296825
H1, H2, H3, H4: MountingHole_Pad; MountingHole_2.7mm_M2.5_DIN965_Pad_TopBottom
J1: Conn_01x06; PinHeader_1x06_P2.54mm_Vertical; not fitted
KEY1, KEY2, KEY3, KEY4, KEY5, KEY6, KEY7, KEY8, KEY9, KEY10, KEY11, KEY12, KEY13, KEY14, KEY15, KEY16, KEY17, KEY18, KEY19, KEY20, KEY21, KEY22, KEY23, KEY24: 28115181DM; hall_key_footprint; LCSC Part C47121944
LED2: SK6812MINI-EA; LED-SMD_4P-L3.2-W2.8_SK6812MINI-EA; LCSC Part C5378731
NT1, NT2: NetTie_2; NetTie-2_SMD_Pad0.5mm
Q1, Q3: AO3401A; SOT-23
R1, R2, R3, R4, R9: 10K; R_0402_1005Metric
R5, R6, R7, R8: 10K; R_0402_1005Metric_Pad0.72x0.64mm_HandSolder
U1, U4, U6, U9, U10, U12, U13, U14, U15, U16, U17, U19, U20, U21, U24, U25, U27, U28, U29, U30, U31, U32, U33, U35: SLSS49E-3; SLSS49E_Hall_Switch_MX; LCSC Part C2904393
U2: ATtiny1616-M; VQFN-20-1EP_3x3mm_P0.4mm_EP1.7x1.7mm
U3, U18, U26, U34: CD4051BM96; SOIC-16_L9.9-W3.9-P1.27-LS6.0-BL; LCSC Part C21379
U5, U11: H3V3U10B; DFN1006-2L-BI; LCSC Part C20615782
U7: Pogo Pin Left; CONN-SMD_4P-L11.0-W5.5-P2.50_YZ165615055F-04025-01; LCSC Part C5296819
U8: AP2112K-3.3; SOT-23-5
U22: LM66200DRLR; SOT-583-8_L2.1-W1.2-P0.50-LS1.6-BL; LCSC Part C3235556

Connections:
+3.3V: C1.1, C6.1, J1.2, LED2.1 (VDD), NT1.1, NT2.1, R1.1, R2.1, R3.1, U2.4 (VCC), U8.5 (VOUT)
A0: R5.1, U2.5 (PA4), U3.3 (COMOUT/IN)
A1: R6.1, U2.6 (PA5), U18.3 (COMOUT/IN)
A2: R7.1, U2.7 (PA6), U26.3 (COMOUT/IN)
A3: R8.1, U2.8 (PA7), U34.3 (COMOUT/IN)
A3.3V: C2.1, C3.1, C4.1, C5.1, NT1.2, NT2.2, U1.1 (VDD), U3.16 (VDD), U4.1 (VDD), U6.1 (VDD), U9.1 (VDD), U10.1 (VDD), U12.1 (VDD), U13.1 (VDD), U14.1 (VDD), U15.1 (VDD), U16.1 (VDD), U17.1 (VDD), U18.16 (VDD), U19.1 (VDD), U20.1 (VDD), U21.1 (VDD), U24.1 (VDD), U25.1 (VDD), U26.16 (VDD), U27.1 (VDD), U28.1 (VDD), U29.1 (VDD), U30.1 (VDD), U31.1 (VDD), U32.1 (VDD), U33.1 (VDD), U34.16 (VDD), U35.1 (VDD)
D11: U2.16 (PC1), U3.11 (A), U18.11 (A), U26.11 (A), U34.11 (A)
D12: U2.17 (PC2), U3.10 (B), U18.10 (B), U26.10 (B), U34.10 (B)
D13: U2.18 (PC3), U3.9 (C), U18.9 (C), U26.9 (C), U34.9 (C)
GND: C1.2, C2.2, C3.2, C4.2, C5.2, C6.2, C7.2, CN3.4, H1.1, H2.1, H3.1, H4.1, J1.1, LED2.3 (GND), R5.2, R6.2, R7.2, R8.2, U1.2 (GND), U2.3 (GND), U2.21 (GND), U3.6 (INH), U3.7 (VEE), U3.8 (VSS), U4.2 (GND), U5.2, U6.2 (GND), U7.1, U8.2 (GND), U9.2 (GND), U10.2 (GND), U11.2, U12.2 (GND), U13.2 (GND), U14.2 (GND), U15.2 (GND), U16.2 (GND), U17.2 (GND), U18.6 (INH), U18.7 (VEE), U18.8 (VSS), U19.2 (GND), U20.2 (GND), U21.2 (GND), U22.1 (GND), U22.4 (~ON), U22.5 (GND), U24.2 (GND), U25.2 (GND), U26.6 (INH), U26.7 (VEE), U26.8 (VSS), U27.2 (GND), U28.2 (GND), U29.2 (GND), U30.2 (GND), U31.2 (GND), U32.2 (GND), U33.2 (GND), U34.6 (INH), U34.7 (VEE), U34.8 (VSS), U35.2 (GND)
NEO: LED2.4 (DIN), U2.10 (PB4)
unnamed: C8.2, Q1.2 (S), Q3.2 (S), R9.1
unnamed: U1.3 (VOUT), U3.15 (CHANNELSIN/OUT2)
unnamed: U3.14 (CHANNELSIN/OUT1), U4.3 (VOUT)
unnamed: U3.12 (CHANNELSIN/OUT3), U6.3 (VOUT)
unnamed: U3.5 (IN/OUT5), U9.3 (VOUT)
unnamed: R4.1, U8.3 (EN)
unnamed: U3.2 (IN/OUT6), U10.3 (VOUT)
unnamed: U12.3 (VOUT), U18.15 (CHANNELSIN/OUT2)
unnamed: U13.3 (VOUT), U18.14 (CHANNELSIN/OUT1)
unnamed: U14.3 (VOUT), U18.1 (CHANNELS4)
unnamed: U15.3 (VOUT), U18.13 (CHANNELSIN/OUT0)
unnamed: U16.3 (VOUT), U18.2 (IN/OUT6)
unnamed: U17.3 (VOUT), U18.12 (CHANNELSIN/OUT3)
unnamed: U18.5 (IN/OUT5), U19.3 (VOUT)
unnamed: U20.3 (VOUT), U26.15 (CHANNELSIN/OUT2)
unnamed: U21.3 (VOUT), U26.14 (CHANNELSIN/OUT1)
unnamed: U24.3 (VOUT), U26.2 (IN/OUT6)
unnamed: U25.3 (VOUT), U26.12 (CHANNELSIN/OUT3)
unnamed: U26.5 (IN/OUT5), U27.3 (VOUT)
unnamed: U28.3 (VOUT), U34.15 (CHANNELSIN/OUT2)
unnamed: U29.3 (VOUT), U34.14 (CHANNELSIN/OUT1)
unnamed: U30.3 (VOUT), U34.1 (CHANNELS4)
unnamed: U31.3 (VOUT), U34.13 (CHANNELSIN/OUT0)
unnamed: U32.3 (VOUT), U34.2 (IN/OUT6)
unnamed: U33.3 (VOUT), U34.12 (CHANNELSIN/OUT3)
unnamed: U34.5 (IN/OUT5), U35.3 (VOUT)
PWR: C8.1, Q1.1 (G), Q3.1 (G), R9.2, U2.9 (PB5)
RXD: U2.11 (PB3)
SCL0: CN3.1, J1.5, R2.2, U2.14 (PB0), U7.4, U11.1
SDA0: CN3.2, J1.4, R3.2, U2.13 (PB1), U5.1, U7.3
TXD: J1.6, U2.12 (PB2)
UPDI: J1.3, R1.2, U2.19 (~RESET/PA0)
VBUS: C7.1, R4.2, U8.1 (VIN), U22.2 (VOUT), U22.7 (VOUT)
VBUS0: Q1.3 (D), U7.2, U22.6 (VIN2)
VBUS1: CN3.3, Q3.3 (D), U22.3 (VIN1)

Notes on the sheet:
Power transmission circuit
NeoPixel (reverse-mount)
UPDI/debug header

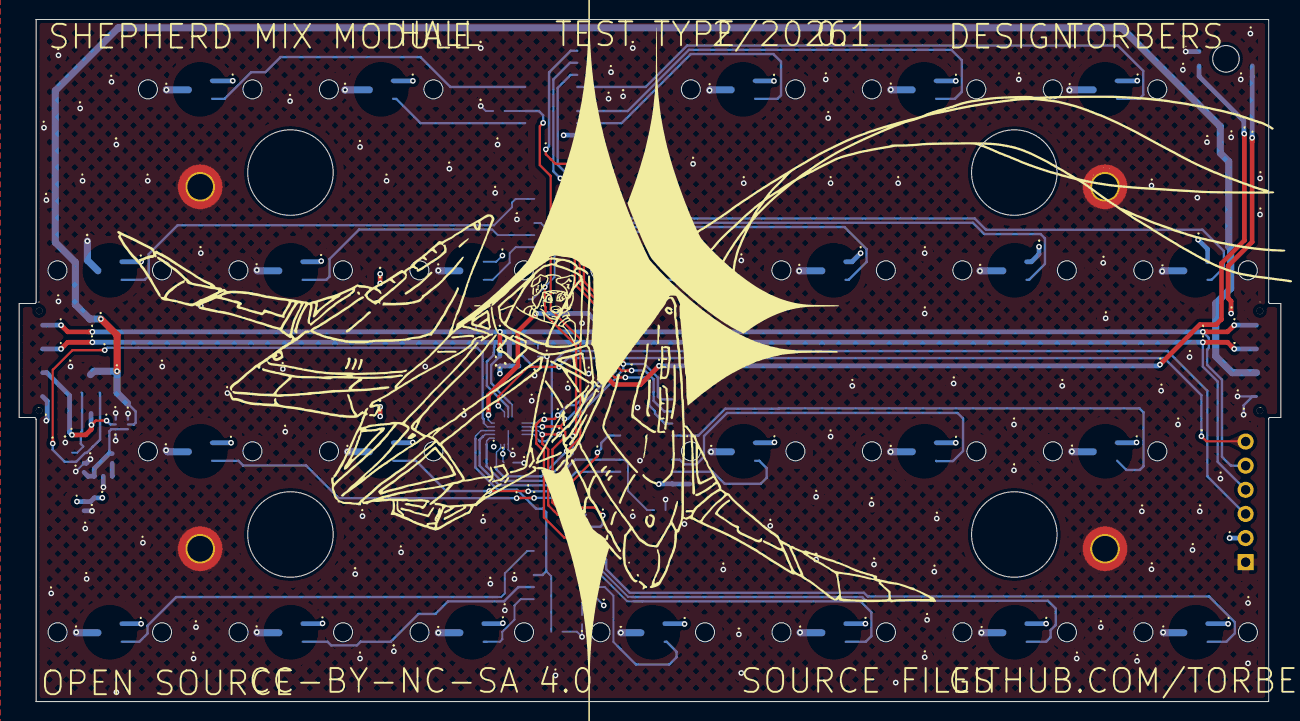
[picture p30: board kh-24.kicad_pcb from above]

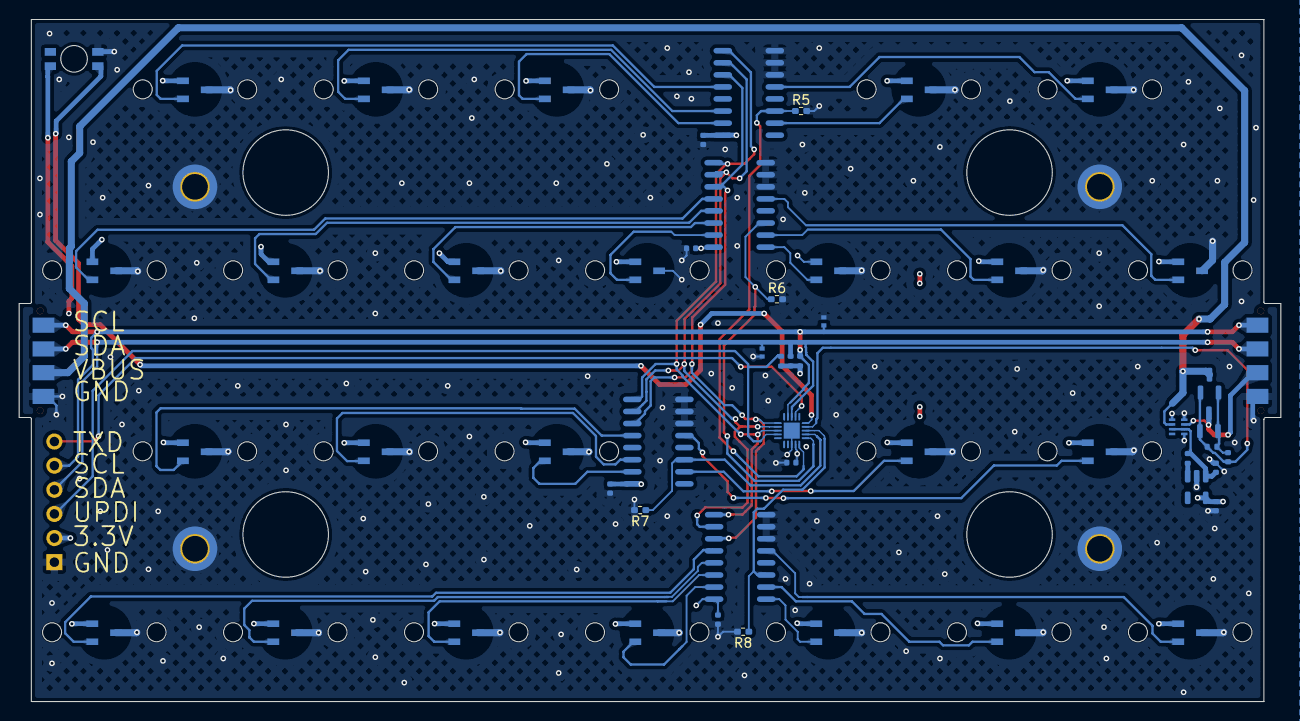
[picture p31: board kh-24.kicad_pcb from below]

Board: 4 copper layers, 132.8 x 71.8 mm, 86 parts (60 on the bottom side), 45 nets.

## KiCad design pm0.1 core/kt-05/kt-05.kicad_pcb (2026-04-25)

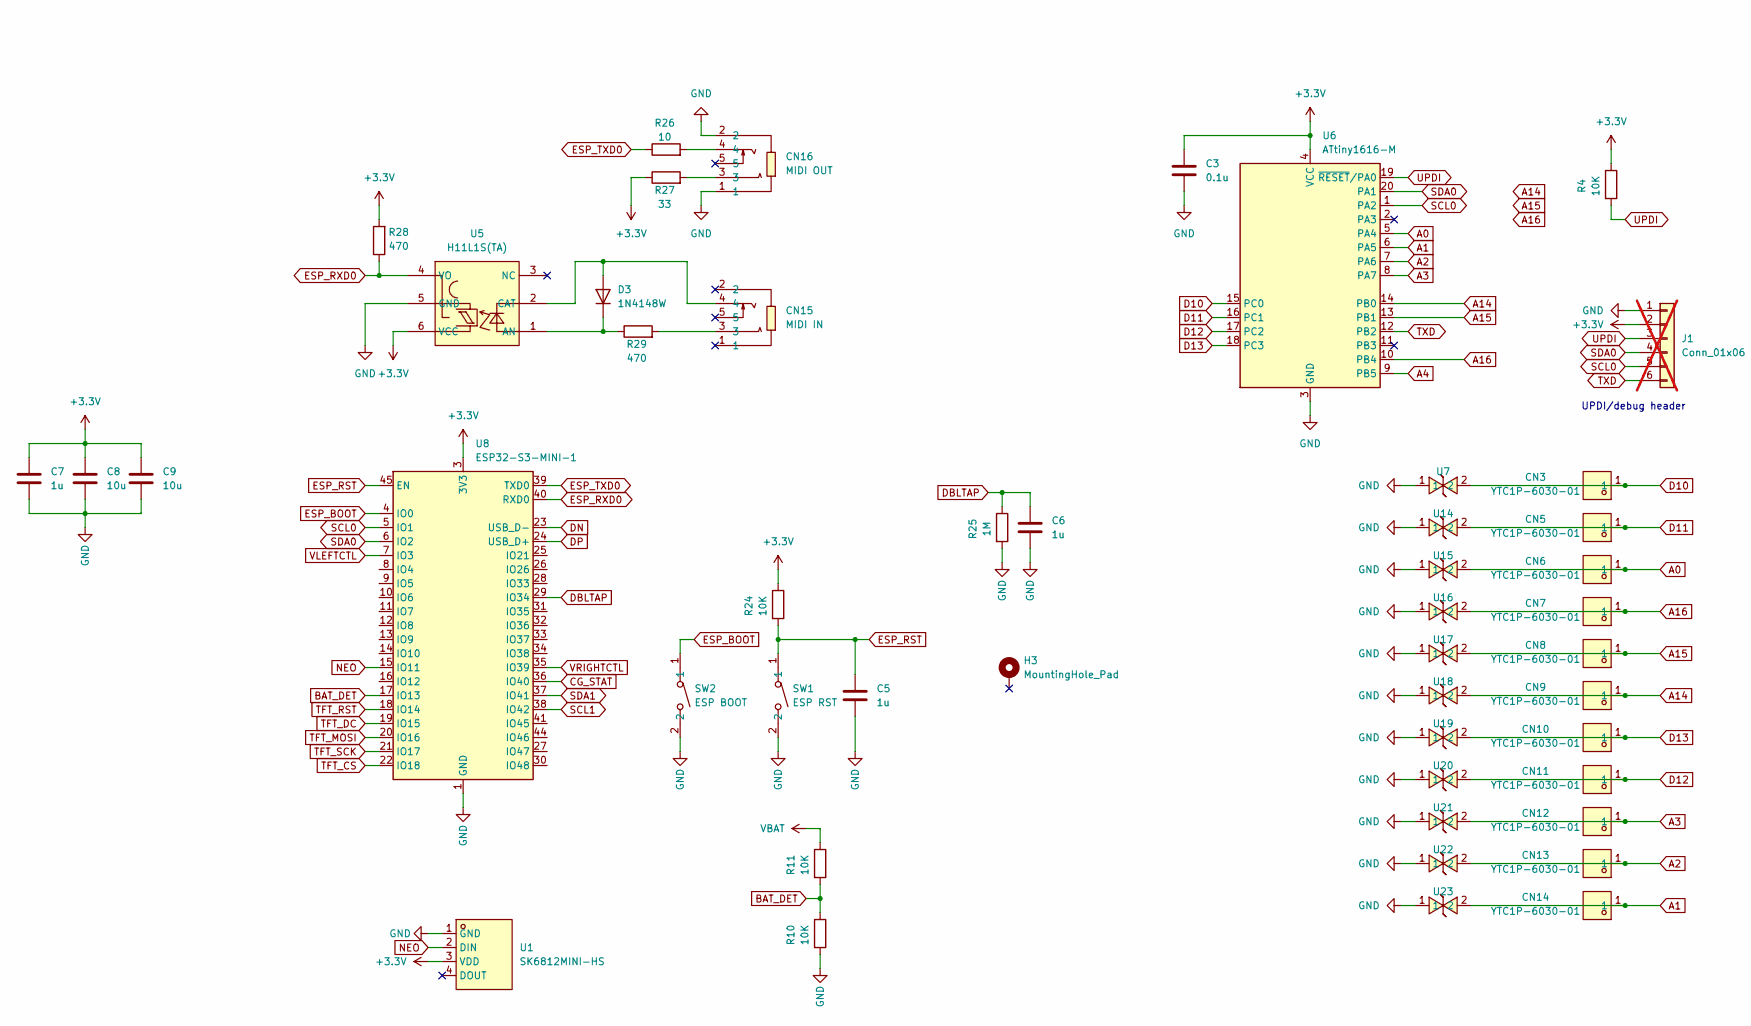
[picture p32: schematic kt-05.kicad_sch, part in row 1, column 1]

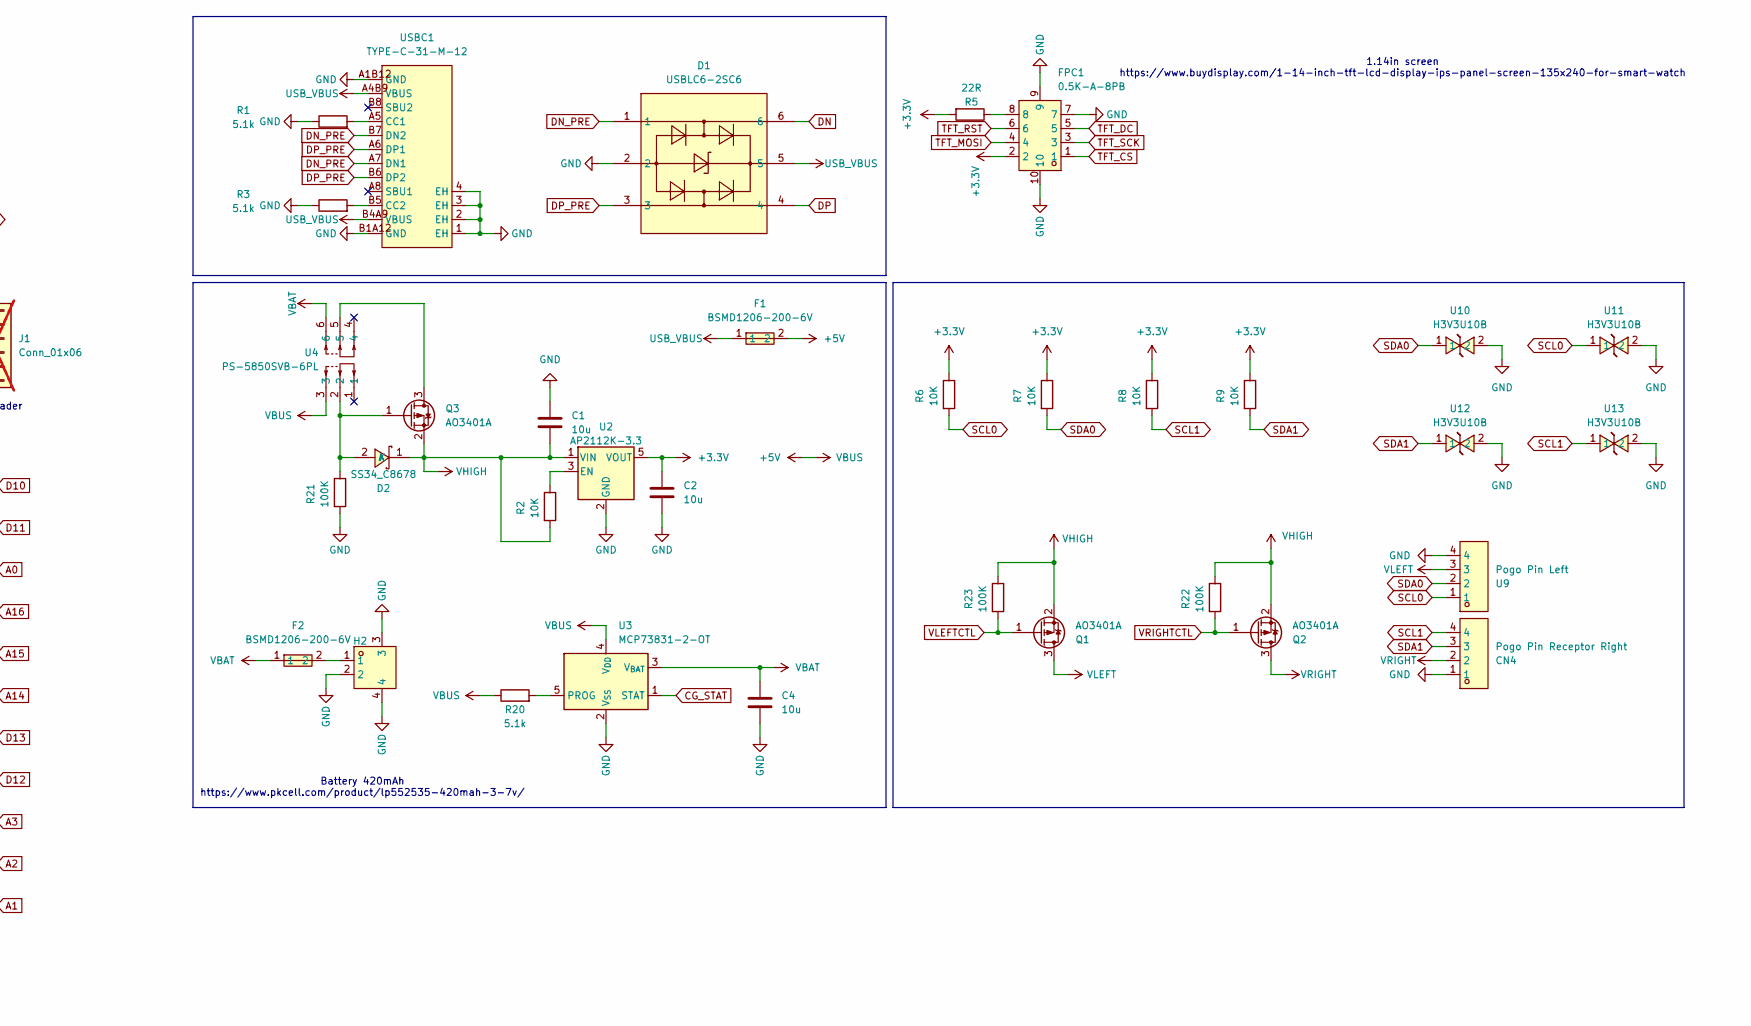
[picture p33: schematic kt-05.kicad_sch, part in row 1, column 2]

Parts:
C1, C2, C4, C8, C9: 10u; C_0402_1005Metric
C3: 0.1u; C_0402_1005Metric
C5, C6, C7: 1u; C_0402_1005Metric
CN3, CN5, CN6, CN7, CN8, CN9, CN10, CN11, CN12, CN13, CN14: YTC1P-6030-01; SMD-1_BD2.0-H10.0; LCSC Part C5221285
CN4: Pogo Pin Receptor Right; CONN-SMD_YZ199315035T-04025-01; LCSC Part C5296825
CN15: MIDI IN; AUDIO-SMD_PJ-327A5JJ; LCSC Part C668605
CN16: MIDI OUT; AUDIO-SMD_PJ-327A5JJ; LCSC Part C668605
D1: USBLC6-2SC6; SOT-23-6_L2.9-W1.6-P0.95-LS2.8-BL; LCSC Part C7519
D2: SS34_C8678; SMA_L4.3-W2.6-LS5.2-RD; LCSC Part C8678
D3: 1N4148W; D_SOD-123
F1, F2: BSMD1206-200-6V; F1206; LCSC Part C883134
FPC1: 0.5K-A-8PB; FPC-SMD_8P-P0.50_HDGC_0.5K-A-8PB; LCSC Part C2914134
H2: WAFER-PH2.0-2PWB; CONN-SMD_2P-P2.00_XUNPU_WAFER-PH2.0-2PWB; LCSC Part C3029440
H3: MountingHole_Pad; MountingHole_2.7mm_M2.5_DIN965_Pad_TopBottom
J1: Conn_01x06; PinHeader_1x06_P2.54mm_Vertical; not fitted
Q1, Q2, Q3: AO3401A; SOT-23
R1, R3, R20: 5.1k; R_0402_1005Metric
R2, R4, R6, R7, R8, R9, R10, R11, R24: 10K; R_0402_1005Metric
R5: 22R; R_0402_1005Metric
R21, R22, R23: 100K; R_0402_1005Metric
R25: 1M; R_0402_1005Metric
R26: 10; R_0402_1005Metric
R27: 33; R_0402_1005Metric
R28, R29: 470; R_0402_1005Metric
SW1: ESP RST; SW-SMD_L3.9-W3.0-P4.45; LCSC Part C720477
SW2: ESP BOOT; SW-SMD_L3.9-W3.0-P4.45; LCSC Part C720477
U1: SK6812MINI-HS; LED-SMD_4P-L3.5-W3.5-BR_SK6812MINI-HS; LCSC Part C2922787
U2: AP2112K-3.3; SOT-23-5
U3: MCP73831-2-OT; SOT-23-5; LCSC ID C424093
U4: PS-5850SVB-6PL; SW-SMD_6P-L5.8-W5.8-P2.00-LS11.3; LCSC Part C5155567
U5: H11L1S(TA); SMD-6_L7.3-W6.5-P2.54-LS10.2-BL; LCSC Part C78589
U6: ATtiny1616-M; VQFN-20-1EP_3x3mm_P0.4mm_EP1.7x1.7mm
U7, U10, U11, U12, U13, U14, U15, U16, U17, U18, U19, U20, U21, U22, U23: H3V3U10B; DFN1006-2L-BI; LCSC Part C20615782
U8: ESP32-S3-MINI-1; ESP32-S2-MINI-1
U9: Pogo Pin Left; CONN-SMD_4P-L11.0-W5.5-P2.50_YZ165615055F-04025-01; LCSC Part C5296819
USBC1: TYPE-C-31-M-12; USB-C_SMD-TYPE-C-31-M-12_1; LCSC Part C165948

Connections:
+3.3V: C2.1, C3.1, C7.1, C8.1, C9.1, FPC1.2, J1.2, R4.1, R5.2, R6.1, R7.1, R8.1, R9.1, R24.1, R27.1, R28.2, U1.3 (VDD), U2.5 (VOUT), U5.6 (VCC), U6.4 (VCC), U8.3 (3V3)
A0: CN6.1, U6.5 (PA4), U15.2
A1: CN14.1, U6.6 (PA5), U23.2
A2: CN13.1, U6.7 (PA6), U22.2
A3: CN12.1, U6.8 (PA7), U21.2
A4: U6.9 (PB5)
A14: CN9.1, U6.14 (PB0), U18.2
A15: CN8.1, U6.13 (PB1), U17.2
A16: CN7.1, U6.10 (PB4), U16.2
BAT_DET: R10.1, R11.2, U8.17 (IO13)
CG_STAT: U3.1 (STAT), U8.36 (IO40)
D10: CN3.1, U6.15 (PC0), U7.2
D11: CN5.1, U6.16 (PC1), U14.2
D12: CN11.1, U6.17 (PC2), U20.2
D13: CN10.1, U6.18 (PC3), U19.2
DBLTAP: C6.1, R25.1, U8.29 (IO34)
DN: D1.6, U8.23 (USB_D-)
DN_PRE: D1.1, USBC1.A7 (DN1), USBC1.B7 (DN2)
DP: D1.4, U8.24 (USB_D+)
DP_PRE: D1.3, USBC1.A6 (DP1), USBC1.B6 (DP2)
ESP_BOOT: SW2.1, U8.4 (IO0)
ESP_RST: C5.1, R24.2, SW1.1, U8.45 (EN)
ESP_RXD0: R28.1, U5.4 (VO), U8.40 (RXD0)
ESP_TXD0: R26.1, U8.39 (TXD0)
GND: C1.2, C2.2, C3.2, C4.2, C5.2, C6.2, C7.2, C8.2, C9.2, CN4.1, CN16.1, CN16.2, D1.2, FPC1.7, FPC1.9, FPC1.10, H2.2, H2.3, H2.4, J1.1, R1.1, R3.1, R10.2, R21.2, R25.2, SW1.2, SW2.2, U1.1 (GND), U2.2 (GND), U3.2 (V_{SS}), U5.5 (GND), U6.3 (GND), U6.21 (GND), U7.1, U8.1 (GND), U8.2 (GND), U8.42 (GND), U8.43 (GND), U8.46 (GND), U8.47 (GND), U8.48 (GND), U8.49 (GND), U8.50 (GND), U8.51 (GND), U8.52 (GND), U8.53 (GND), U8.54 (GND), U8.55 (GND), U8.56 (GND), U8.57 (GND), U8.58 (GND), U8.59 (GND), U8.60 (GND), U8.61 (GND), U8.62 (GND), U8.63 (GND), U8.64 (GND), U8.65 (GND), U9.4, U10.2, U11.2, U12.2, U13.2, U14.1, U15.1, U16.1, U17.1, U18.1, U19.1, U20.1, U21.1, U22.1, U23.1, USBC1.1 (EH), USBC1.2 (EH), USBC1.3 (EH), USBC1.4 (EH), USBC1.A1B12 (GND), USBC1.B1A12 (GND)
NEO: U1.2 (DIN), U8.15 (IO11)
unnamed: CN15.3, R29.2
unnamed: CN16.3, R27.2
unnamed: CN16.4, R26.2
unnamed: D2.2 (A), Q3.1 (G), R21.1, U4.2
unnamed: CN15.4, D3.2 (A), U5.2 (CAT)
unnamed: D3.1 (K), R29.1, U5.1 (AN)
unnamed: F2.2, H2.1
unnamed: FPC1.8, R5.1
unnamed: Q3.3 (D), U4.5
unnamed: R2.1, U2.3 (EN)
unnamed: R20.2, U3.5 (PROG)
unnamed: R1.2, USBC1.A5 (CC1)
unnamed: R3.2, USBC1.B5 (CC2)
SCL0: J1.5, R6.2, U6.1 (PA2), U8.5 (IO1), U9.1, U11.1
SCL1: CN4.4, R8.2, U8.38 (IO42), U13.1
SDA0: J1.4, R7.2, U6.20 (PA1), U8.6 (IO2), U9.2, U10.1
SDA1: CN4.3, R9.2, U8.37 (IO41), U12.1
TFT_CS: FPC1.1, U8.22 (IO18)
TFT_DC: FPC1.5, U8.19 (IO15)
TFT_MOSI: FPC1.4, U8.20 (IO16)
TFT_RST: FPC1.6, U8.18 (IO14)
TFT_SCK: FPC1.3, U8.21 (IO17)
TXD: J1.6, U6.12 (PB2)
UPDI: J1.3, R4.2, U6.19 (~RESET/PA0)
USB_VBUS: D1.5, F1.1, USBC1.A4B9 (VBUS), USBC1.B4A9 (VBUS)
VBAT: C4.1, F2.1, R11.1, U3.3 (V_{BAT}), U4.6
VLEFT: Q1.3 (D), U9.3
VLEFTCTL: Q1.1 (G), R23.2, U8.7 (IO3)
VRIGHT: CN4.2, Q2.3 (D)
VRIGHTCTL: Q2.1 (G), R22.2, U8.35 (IO39)

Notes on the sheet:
UPDI/debug header
1.14in screen https://www.buydisplay.com/1-14-inch-tft-lcd-display-ips-panel-screen-135x240-for-smart-watch
Battery 420mAh https://www.pkcell.com/product/lp552535-420mah-3-7v/

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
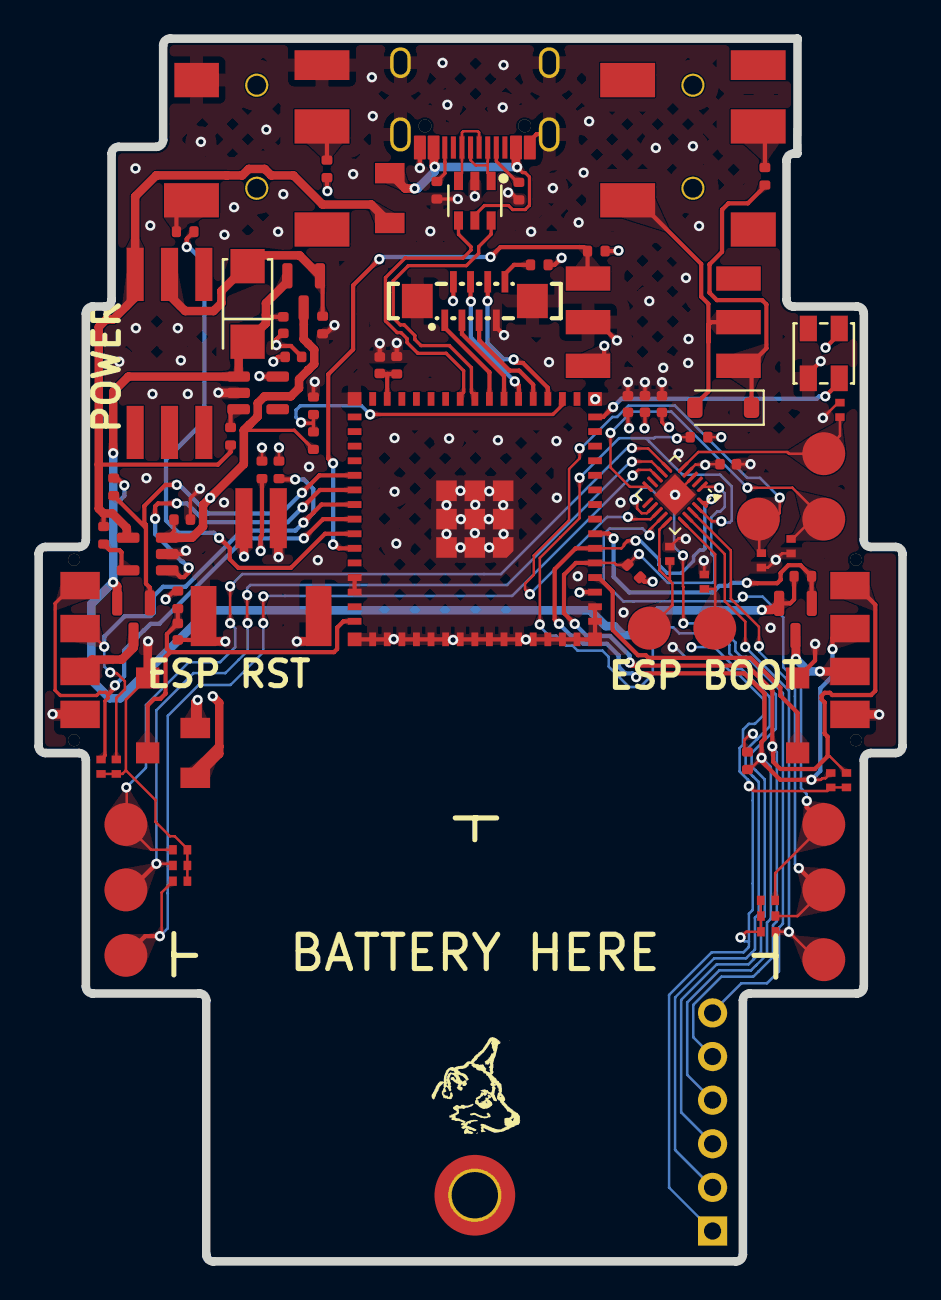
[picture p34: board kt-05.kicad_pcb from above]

Board: 4 copper layers, 50.3 x 71.2 mm, 82 parts (0 on the bottom side), 57 nets.

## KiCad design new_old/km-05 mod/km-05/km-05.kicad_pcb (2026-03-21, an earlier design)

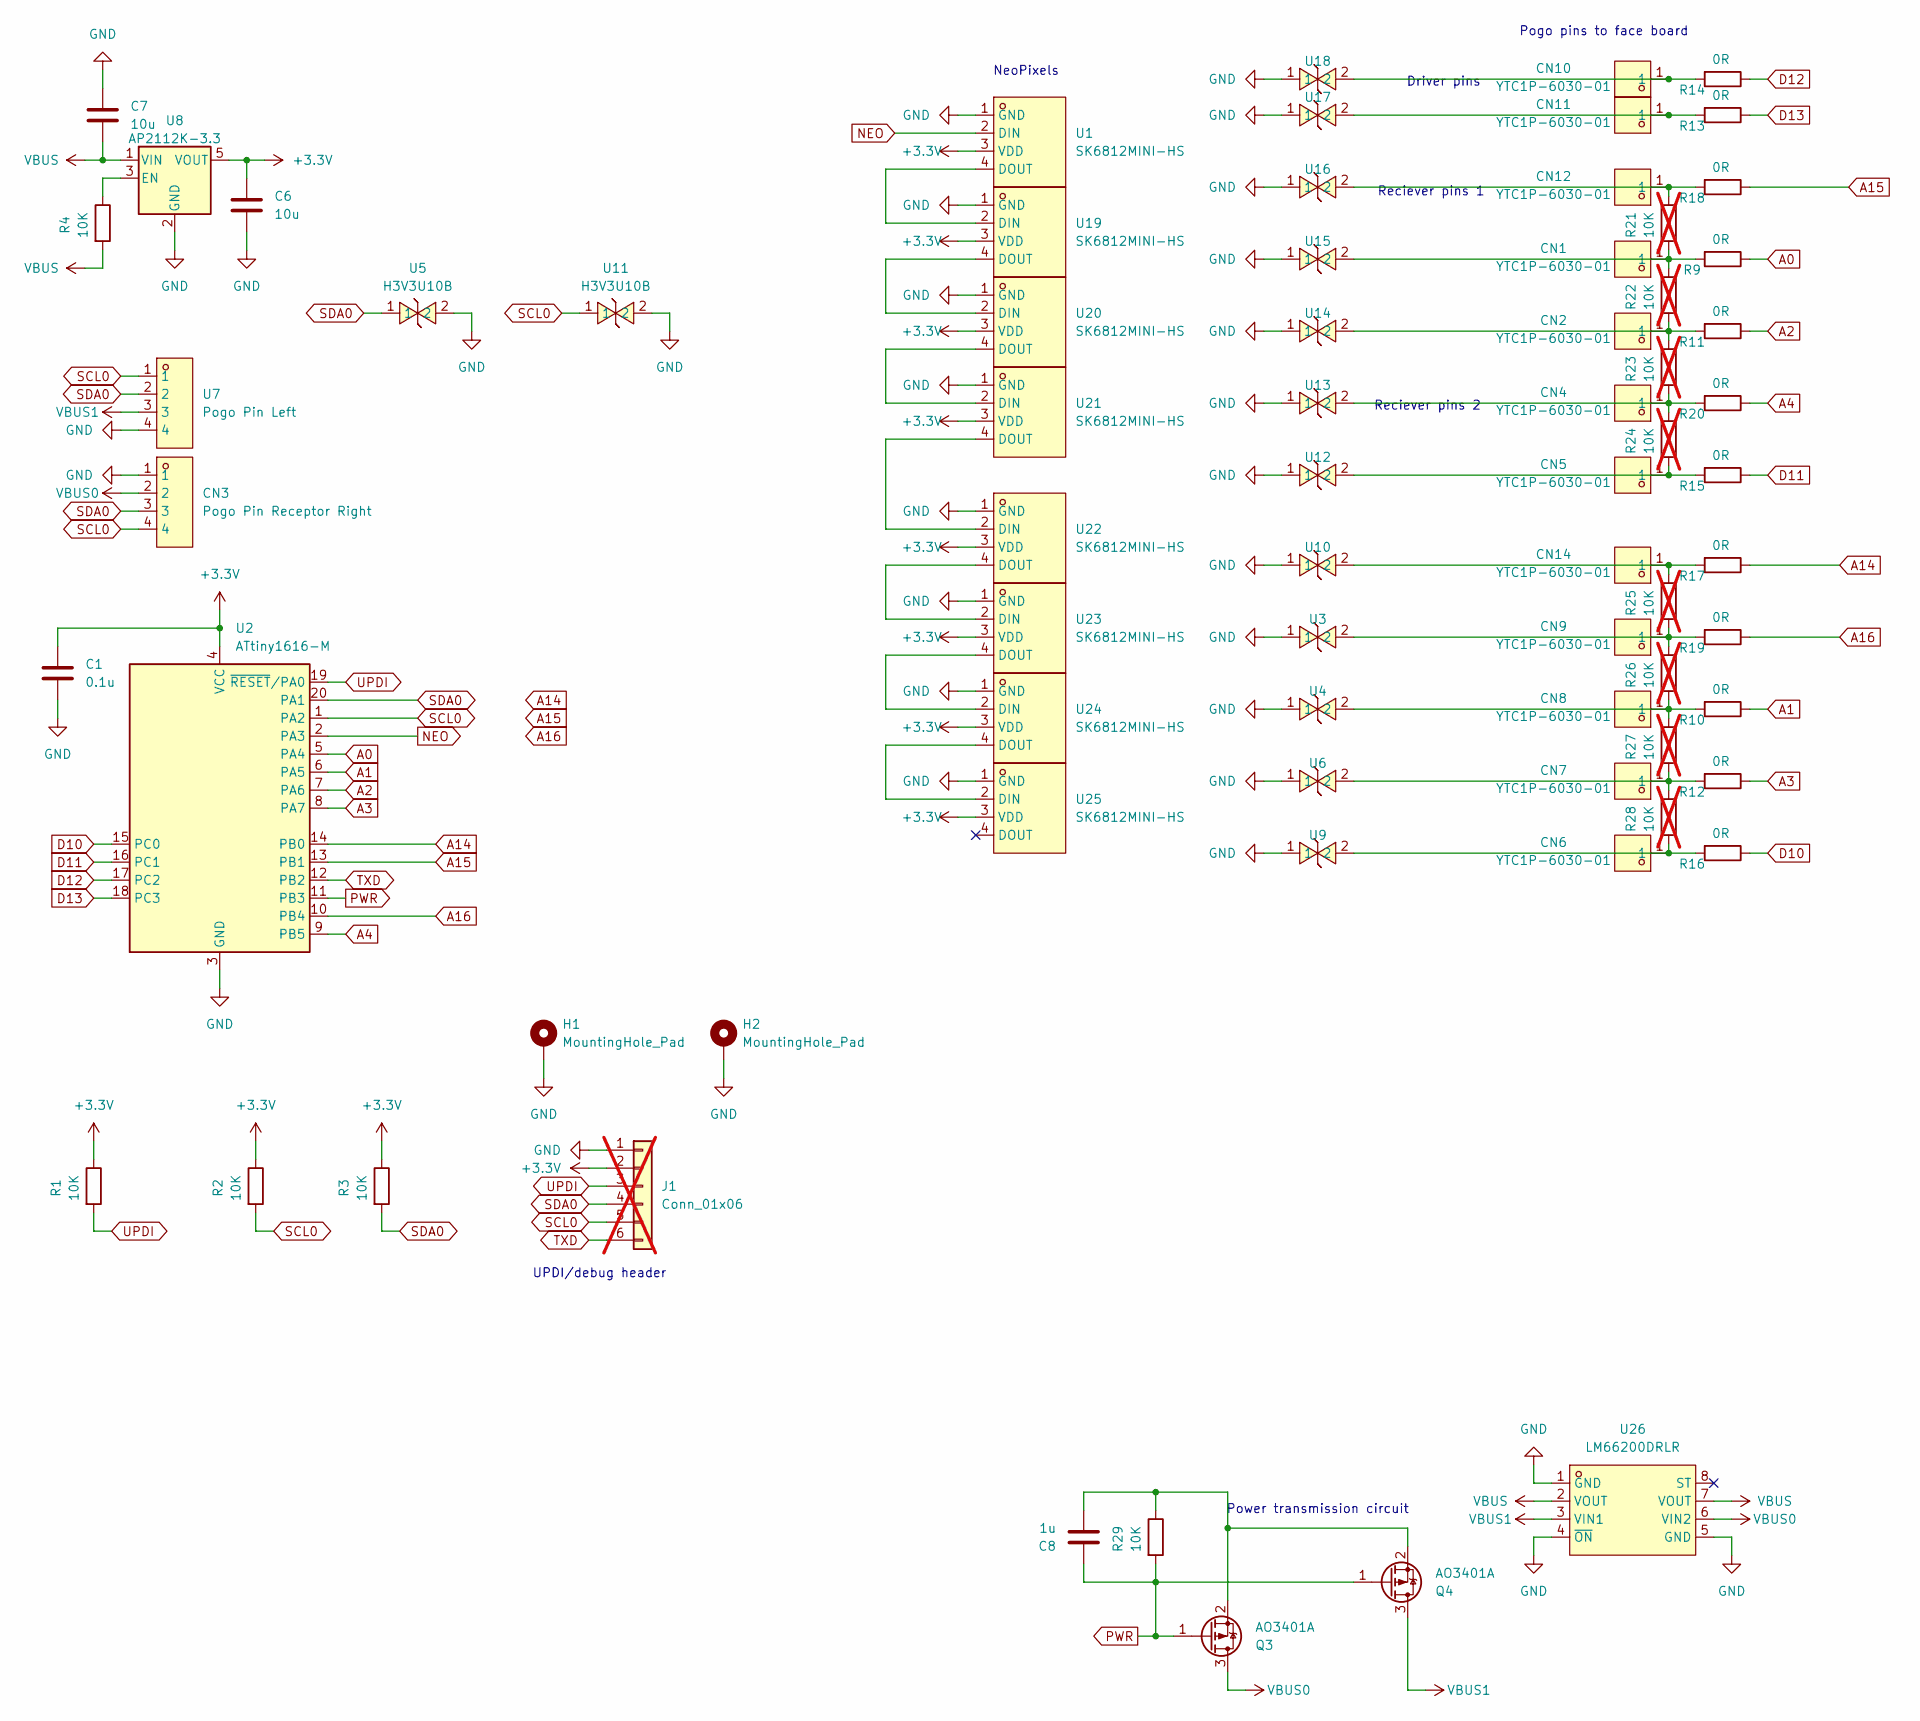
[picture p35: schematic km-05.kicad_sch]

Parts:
C1: 0.1u; C_0402_1005Metric
C6, C7: 10u; C_0402_1005Metric
C8: 1u; C_0402_1005Metric
CN1, CN2, CN4, CN5, CN6, CN7, CN8, CN9, CN10, CN11, CN12, CN14: YTC1P-6030-01; SMD-1_BD2.0-H10.0; LCSC Part C5221285
CN3: Pogo Pin Receptor Right; CONN-SMD_YZ199315035T-04025-01; LCSC Part C5296825
H1, H2: MountingHole_Pad; MountingHole_2.7mm_M2.5_DIN965_Pad_TopBottom
J1: Conn_01x06; PinHeader_1x06_P2.54mm_Vertical; not fitted
Q3, Q4: AO3401A; SOT-23
R1, R2, R3, R4, R29: 10K; R_0402_1005Metric
R9, R10, R11, R12, R13, R14, R15, R16, R17, R18, R19, R20: 0R; R_0402_1005Metric
R21, R22, R23, R24, R25, R26, R27, R28: 10K; R_0402_1005Metric; not fitted
U1, U19, U20, U21, U22, U23, U24, U25: SK6812MINI-HS; LED-SMD_4P-L3.5-W3.5-BR_SK6812MINI-HS; LCSC Part C2922787
U2: ATtiny1616-M; VQFN-20-1EP_3x3mm_P0.4mm_EP1.7x1.7mm
U3, U4, U5, U6, U9, U10, U11, U12, U13, U14, U15, U16, U17, U18: H3V3U10B; DFN1006-2L-BI; LCSC Part C20615782
U7: Pogo Pin Left; CONN-SMD_4P-L11.0-W5.5-P2.50_YZ165615055F-04025-01; LCSC Part C5296819
U8: AP2112K-3.3; SOT-23-5
U26: LM66200DRLR; SOT-583-8_L2.1-W1.2-P0.50-LS1.6-BL; LCSC Part C3235556

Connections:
+3.3V: C1.1, C6.1, J1.2, R1.1, R2.1, R3.1, U1.3 (VDD), U2.4 (VCC), U8.5 (VOUT), U19.3 (VDD), U20.3 (VDD), U21.3 (VDD), U22.3 (VDD), U23.3 (VDD), U24.3 (VDD), U25.3 (VDD)
A0: R9.1, U2.5 (PA4)
A1: R10.1, U2.6 (PA5)
A2: R11.1, U2.7 (PA6)
A3: R12.1, U2.8 (PA7)
A4: R20.1, U2.9 (PB5)
A14: R17.1, U2.14 (PB0)
A15: R18.1, U2.13 (PB1)
A16: R19.1, U2.10 (PB4)
D10: R16.1, U2.15 (PC0)
D11: R15.1, U2.16 (PC1)
D12: R14.1, U2.17 (PC2)
D13: R13.1, U2.18 (PC3)
GND: C1.2, C6.2, C7.2, CN3.1, H1.1, H2.1, J1.1, U1.1 (GND), U2.3 (GND), U2.21 (GND), U3.1, U4.1, U5.2, U6.1, U7.4, U8.2 (GND), U9.1, U10.1, U11.2, U12.1, U13.1, U14.1, U15.1, U16.1, U17.1, U18.1, U19.1 (GND), U20.1 (GND), U21.1 (GND), U22.1 (GND), U23.1 (GND), U24.1 (GND), U25.1 (GND), U26.1 (GND), U26.4 (~ON), U26.5 (GND)
NEO: U1.2 (DIN), U2.2 (PA3)
unnamed: CN1.1, R9.2, R21.2, R22.1, U15.2
unnamed: CN2.1, R11.2, R22.2, R23.1, U14.2
unnamed: CN4.1, R20.2, R23.2, R24.1, U13.2
unnamed: CN5.1, R15.2, R24.2, U12.2
unnamed: CN6.1, R16.2, R28.2, U9.2
unnamed: CN7.1, R12.2, R27.2, R28.1, U6.2
unnamed: CN8.1, R10.2, R26.2, R27.1, U4.2
unnamed: CN9.1, R19.2, R25.2, R26.1, U3.2
unnamed: CN10.1, R14.2, U18.2
unnamed: CN11.1, R13.2, U17.2
unnamed: CN12.1, R18.2, R21.1, U16.2
unnamed: CN14.1, R17.2, R25.1, U10.2
unnamed: C8.2, Q3.2 (S), Q4.2 (S), R29.1
unnamed: U1.4 (DOUT), U19.2 (DIN)
unnamed: R4.1, U8.3 (EN)
unnamed: U19.4 (DOUT), U20.2 (DIN)
unnamed: U20.4 (DOUT), U21.2 (DIN)
unnamed: U21.4 (DOUT), U22.2 (DIN)
unnamed: U22.4 (DOUT), U23.2 (DIN)
unnamed: U23.4 (DOUT), U24.2 (DIN)
unnamed: U24.4 (DOUT), U25.2 (DIN)
PWR: C8.1, Q3.1 (G), Q4.1 (G), R29.2, U2.11 (PB3)
SCL0: CN3.4, J1.5, R2.2, U2.1 (PA2), U7.1, U11.1
SDA0: CN3.3, J1.4, R3.2, U2.20 (PA1), U5.1, U7.2
TXD: J1.6, U2.12 (PB2)
UPDI: J1.3, R1.2, U2.19 (~RESET/PA0)
VBUS: C7.1, R4.2, U8.1 (VIN), U26.2 (VOUT), U26.7 (VOUT)
VBUS0: CN3.2, Q3.3 (D), U26.6 (VIN2)
VBUS1: Q4.3 (D), U7.3, U26.3 (VIN1)

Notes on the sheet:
Reciever pins 1
Reciever pins 2
NeoPixels
Power transmission circuit
Driver pins
Pogo pins to face board
UPDI/debug header

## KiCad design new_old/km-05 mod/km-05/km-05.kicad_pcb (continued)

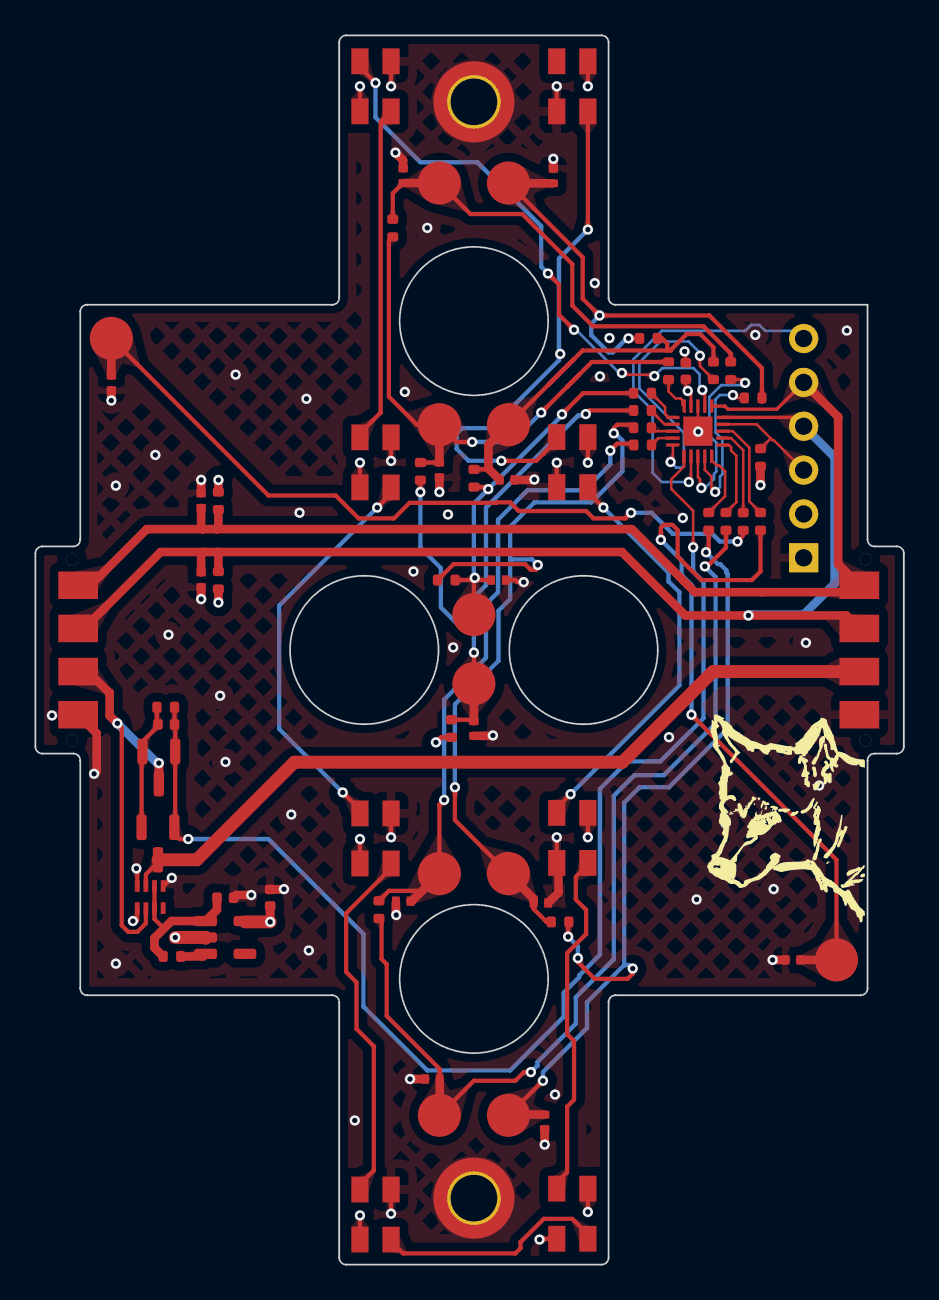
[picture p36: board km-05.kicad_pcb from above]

Board: 4 copper layers, 50.3 x 71.2 mm, 73 parts (0 on the bottom side), 44 nets.

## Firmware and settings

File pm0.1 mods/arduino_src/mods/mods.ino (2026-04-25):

//void README() {
//  return;

  /*
  Dual capacitive touch slider keyboard peripheral module
  Part of Shepherd System
  by Sam Kothe (torbers)

  Senses state and position of two 6-sensor ATTiny PTC capacitive touch sliders and makes available via I2C.


  Hardware:
    Microcontroller: ATTINYx16
    Sensors tied directly to microcontroller pins (with ESD protection).


  I2C Register Map:
    0x00: Slider 1 raw
    0x01: Slider 2 raw
    0x02: Slider 1 hysteresis
    0x03: Slider 2 hysteresis

    0x04: Slider 1 magnitude
    0x05: Slider 2 magnitude
    0x06: Slider 1 magnitude hysteresis
    0x07: Slider 2 magnitude hysteresis


  I2C Address Allocation

    Controller routine (each ~200ms)
      Controller sends test address (0x09 for example)
        0x08 WRITE 0xFF 0x01 0x09 STOP
      
      Controller tests address
        0x09
        WRITE
        0xFF (switch to control register)
        0x00 (pointer = 0x00)
        0x00 (write 0x00)
        0x09 (write expected address)
      
      Controller sets pointer
        0x09 WRITE 0xFF (switch to control register)
      
      Controller requests 2 bytes
        0x00 0x09
      
      Recieves 0x09 as expected
    
    Device startup
      Begin Wire on 0x08
      Recieve message from controller
      Switch to assigned address
      Enable power on next device


  Control register:
  0x00 0x00
  0x01 I2C Address
  0x02 0x01 (Module codename)
  0x03 Enable power = 0x01
  
  0x08..0x20 LED color 1
  0x21..0x39 LED color 2

  */
//}

#include "Hysteresis.h"
#include <Wire.h>
#include <ptc_touch.h>

#include <tinyNeoPixel.h>


#define NODE_COUNT 6


#define DEVICE_ADDR 0x69
#define REGISTER_SIZE 0xFF
#define C_REGISTER_SIZE 0x0F

#define NEOPIXEL_PIN 16
#define PowerSwitchPin 6

#define NUMPIXELS 8


volatile uint8_t DeviceRegisters[REGISTER_SIZE];
volatile uint8_t ControlRegisters[C_REGISTER_SIZE];
volatile uint8_t WirePointer = 0;

unsigned long us;
unsigned long nus;

volatile uint8_t NewAddress = 0x00;
volatile uint8_t af = 0x00;


bool NeoUpdate = false;
uint8_t NeoColors[24];

tinyNeoPixel pixels = tinyNeoPixel(NUMPIXELS, NEOPIXEL_PIN, NEO_GRB + NEO_KHZ800);


// Assigning numbers to modules' codenames in Shepherd System
#define KT05   0x00 // This control module
#define KH24   0x01 // 24-key hall keyboard
#define KC02   0x02 // 2-channel pitch bend/mod/cc controller

//#define DEBUG_SERIAL
//#define WIRE_DEBUG


// slider logic
// adapted from https://github.com/TinyCircuits/TinyCircuits-ATtiny841-Library/tree/master
class Slider {
  public:
    //Slider();
    uint8_t begin(uint8_t *sensors, uint8_t driver);
    int16_t capTouchRead(uint8_t pin);
    int16_t getPosition(int range=0xFF);
    int16_t getMaxReading();
    int16_t getMagnitude();
    uint8_t getPositionHysteresis();
    uint8_t getMagnitudeHysteresis();
    
    uint32_t duration();
    bool update();
    bool isTouched();
    
    static const uint8_t numSensors = NODE_COUNT;
    uint8_t capTouchPins[numSensors] = {};
    uint8_t driver_pin = 0;

    int16_t capTouchCal[numSensors];
    int16_t capTouchCurrent[numSensors];
    uint8_t overCalCount[numSensors];

    int16_t currentMaxReading= 0;
    uint8_t primary = 0;
    bool isTouch = 0;
    uint8_t initialTouchPos = 0;
    uint8_t finalTouchPos = 0;
    uint8_t currentTouchedPositions = 0;
    uint8_t allTouchedPositions = 0;
    uint32_t touchTimer = 0;

    cap_sensor_t s_nodes[numSensors];

    Hysteresis <int16_t> positionHysteresis = Hysteresis <int16_t> (4);
    Hysteresis <int16_t> magnitudeHysteresis = Hysteresis <int16_t> (4);
};

uint8_t Slider::begin(uint8_t sensors[numSensors], uint8_t driver) {

  driver_pin = driver;
  
  for (uint8_t p = 0; p < numSensors; p++) {
    Serial.print("Sensor no.: ");
    Serial.println(p);
    capTouchPins[p] = sensors[p];
    Serial.print("goes to pin no.: ");
    Serial.println(capTouchPins[p]);
  }

  for (uint8_t pin = 0; pin < numSensors; pin++) {
    ptc_add_selfcap_node(&s_nodes[pin], PIN_TO_PTC(capTouchPins[pin]), PIN_TO_PTC(driver_pin));
    delay(100);
  }

  ptc_process(millis());

  for (uint8_t pin = 0; pin < numSensors; pin++) {
    capTouchCal[pin] = capTouchRead(pin);
    overCalCount[pin] = 0;
    delay(100);
  }

  for (uint8_t p = 0; p < numSensors; p++) {
    Serial.print("Sensor read: ");
    Serial.println(capTouchCal[p]);
  }
  
  return 0;
}

int16_t Slider::capTouchRead(uint8_t pin) {
  //return ptc_get_node_sensor_value(&s_nodes[capTouchPins[pin] - 1]);
  return ptc_get_node_sensor_value(&s_nodes[pin]) - 512;
}

int16_t Slider::getPosition(int range) {
  float position = primary;
  if (primary < numSensors-1)
    position += (pow((float)capTouchCurrent[primary + 1] / (float)getMaxReading(),0.45)) / 2.0;
  if (primary > 0)
    position -= (pow((float)capTouchCurrent[primary - 1] / (float)getMaxReading(),0.45)) / 2.0;
  
  position = position * (float)range / float(numSensors-1);
  return position;
}

int16_t Slider::getMaxReading() {
  return currentMaxReading;
}

int16_t Slider::getMagnitude() {
  uint8_t j;
  long magnitude = 0;
  for (j = 0; j < 6; j++) {
    magnitude += pow(capTouchCurrent[j], 2);
  }
  return sqrt(magnitude);
}

uint8_t Slider::getPositionHysteresis() {
  Serial.println(getPosition());
  int16_t ph = positionHysteresis.add(getPosition());
  Serial.println(ph);
  return ph;
}

uint8_t Slider::getMagnitudeHysteresis() {
  return magnitudeHysteresis.add(getMagnitude());
}

bool Slider::update() {
  uint8_t j;
  currentMaxReading=0;
  for (j = 0; j < numSensors; j++) {
    int val = capTouchRead(j);
    if (val < capTouchCal[j]) {
      capTouchCal[j] = val;
    } else if (val > capTouchCal[j] + 1) {
      overCalCount[j]++;
      if (overCalCount[j] > 3) {
        overCalCount[j] = 0;
        capTouchCal[j] += 1;
      } else {
        //overCalCount[j]=0;
      }
    }
    capTouchCurrent[j] = val  - capTouchCal[j];  
    if (capTouchCurrent[j] > getMaxReading()) {
      currentMaxReading = capTouchCurrent[j];
      primary = j;
    }
  }

  bool completedTouch = false;

  if (currentMaxReading > 255) {
    if (!isTouch) {
      isTouch = true;
      touchTimer = millis();
      initialTouchPos = primary;
      finalTouchPos = primary;
      currentTouchedPositions = 0;
      allTouchedPositions = 0;
    } else {
      finalTouchPos = primary;
      currentTouchedPositions = 0;
      for (j = 0; j < numSensors; j++) {
        if (capTouchCurrent[j] > 64)
          currentTouchedPositions |= (1 << j);
        allTouchedPositions |= (1 << j);
      }
    }
  } else {
    if (isTouch) {
      isTouch = false;
      touchTimer = millis() - touchTimer;
      completedTouch = true;
    }
  }

  return completedTouch;
}

bool Slider::isTouched() {
  return isTouch;
}

uint32_t Slider::duration() {
  if (isTouch) {
    return millis() - touchTimer;
  }
  return touchTimer;
}


// I2C Functions

uint8_t startupAddressAlloc(){
  Wire.begin(0x08);
  Serial.println("Wire started on 0x08");
  Wire.onReceive(startupWireHandler);
  Serial.println("Handler set");
  while (!af) {Serial.println(millis()); delay(10);}
  Serial.println(NewAddress);
  
  return NewAddress;
}

void startupWireHandler(int nb) {
  if (Wire.read() == 0xFF) { 
    #ifdef WIRE_DEBUG
      Serial.println("Recieved 0xFF");
    #endif
    if (Wire.read() == 0x01) {
      #ifdef WIRE_DEBUG
        Serial.println("Recieved 0x01");
      #endif
      NewAddress = Wire.read();
      #ifdef WIRE_DEBUG
        Serial.print("Recieved new addr: 0d");
        Serial.println(NewAddress);
      #endif
      delay(1);
      #ifdef WIRE_DEBUG
        Serial.println("Writing 0xd");
      #endif
      Wire.write(0x00); 
      #ifdef WIRE_DEBUG
        Serial.print("Writing 0d");
        Serial.println(NewAddress);
      #endif
      Wire.write(NewAddress);
      delay(10);
      af = 1;
    }
  }
}

void receiveHandler(int numbytes){
  // Handle writes to registers from I2C controller
  // Modified by me from original by SpenceKonde
  uint8_t ReadData;
  Wire.getBytesRead();
  WirePointer = Wire.read();

  #ifdef WIRE_DEBUG
    Serial.println();
    Serial.println("Recieve handler");

    Serial.println(millis());
    Serial.print("Pointer: 0d");
    Serial.println(WirePointer);
  #endif

  if (WirePointer == 0xFF) {
      #ifdef WIRE_DEBUG
        Serial.println("Control register selected");
      #endif

      numbytes--;
      if (Wire.available()){
        WirePointer = Wire.read();
      }
      else {return;}

      #ifdef WIRE_DEBUG
        Serial.print("Ctl addr: 0d");
        Serial.println(WirePointer);
      #endif

      numbytes--;
      while (numbytes > 0) {
        ReadData = Wire.read();
        #ifdef WIRE_DEBUG
          Serial.print("Recieved into register: 0d"); Serial.println(ReadData);
        #endif
        ControlRegisters[WirePointer] = ReadData;
        if (WirePointer >= 0x08) {NeoColors[WirePointer - 0x08] = ReadData; NeoUpdate = true;}
        WirePointer++;
        numbytes--;
    }
    return;
  }

  numbytes--;
    while (numbytes > 0) {
      ReadData = Wire.read();
      DeviceRegisters[WirePointer] = ReadData;
      WirePointer++;
      numbytes--;
    }
}

void requestHandler(){
  uint8_t bytes_read = Wire.getBytesRead();
  #ifdef WIRE_DEBUG
    Serial.println();
    Serial.println("Request handler");
    Serial.print("Bytes read: ");
    Serial.println(bytes_read);
    Serial.print("Pointer: ");
    Serial.println(WirePointer);
  #endif

  WirePointer += bytes_read;
  // Update last-read values
  if (WirePointer == 0xC0) {
    for (uint8_t k = 0; k < 0x20; k++) {DeviceRegisters[k + 0xA0] = DeviceRegisters[k + 0x20];}
  }

  if (WirePointer == 0xFF) {
    #ifdef WIRE_DEBUG
      Serial.println("Control register selected for read");
    #endif
    for (byte i = 0; i < C_REGISTER_SIZE; i++) {
      if (i > C_REGISTER_SIZE) {return;}
      #ifdef WIRE_DEBUG
        Serial.print("Writing to Wire: 0d");
        Serial.println(ControlRegisters[i]);
      #endif
      Wire.write(ControlRegisters[i]);
    }
    return;
  }



  for (byte i = 0; i < REGISTER_SIZE; i++) {
    if (WirePointer + i > REGISTER_SIZE) {return;}
    Wire.write(DeviceRegisters[WirePointer + i]);
    #ifdef WIRE_DEBUG
      Serial.print("Reading to I2C: ");
      Serial.println(WirePointer + i);
      Serial.print("Result: ");
      Serial.println(DeviceRegisters[WirePointer + i]);
    #endif

    // Clear queue
    if (WirePointer + i >= 0xC0) {DeviceRegisters[WirePointer + i] = 0x00;}
  }

}


Slider slider1;
Slider slider2;
uint8_t slider1Pins[NODE_COUNT] = {PIN_PA5, PIN_PA6, PIN_PA7, PIN_PB5, PIN_PB4, PIN_PC1};
uint8_t slider2Pins[NODE_COUNT] = {PIN_PA5, PIN_PA6, PIN_PA7, PIN_PB5, PIN_PB4, PIN_PC1};
uint8_t slider1Driver = 12;
uint8_t slider2Driver = 13;


void setup() {
  // Disable power to next module
  pinMode(PowerSwitchPin, OUTPUT);
  digitalWrite(PowerSwitchPin, HIGH);

  Serial.begin(115200);
  Serial.println("Serial ok");

  pixels.begin();
  pixels.clear();
  for (int i=0; i<8; i++) {pixels.setPixelColor(i, pixels.Color(i*8, 0, 255));}
  pixels.show();

  // Do address allocation; begin Wire
  delay(100);
  ControlRegisters[0x02] = KC02; // Set module type
  while (!NewAddress) {startupAddressAlloc();}
  Wire.end();
  Serial.print("Beginning wire on 0x");
  Serial.println(NewAddress);
  Wire.begin(NewAddress);

  // Handlers for I2C
  Serial.println("Assigning handlers");
  Wire.onReceive(receiveHandler);
  Wire.onRequest(requestHandler);
  delay(200);

  slider1.begin(slider1Pins, slider1Driver);
  slider2.begin(slider2Pins, slider2Driver);

  Serial.println("Beginning main loop");

}


void loop() {
  us = nus;
  nus = micros();

  ptc_process(millis());
  slider1.update();
  slider2.update();

  DeviceRegisters[0x00] = slider1.getPosition();
  DeviceRegisters[0x01] = slider2.getPosition();
  DeviceRegisters[0x02] = slider1.getPositionHysteresis();
  DeviceRegisters[0x03] = slider2.getPositionHysteresis();

  DeviceRegisters[0x04] = slider1.getMagnitude();
  DeviceRegisters[0x05] = slider2.getMagnitude();
  DeviceRegisters[0x06] = slider1.getMagnitudeHysteresis();
  DeviceRegisters[0x07] = slider2.getMagnitudeHysteresis();

  #ifdef DEBUG_SERIAL
  Serial.print(", Slider 1 pos h:");
  Serial.print(DeviceRegisters[0x00]);
  Serial.print(", Slider 2 pos h:");
  Serial.print(DeviceRegisters[0x01]);

  Serial.print(", max:");
  Serial.print(0xFF);
  Serial.print(", min:");
  Serial.println(0);

  #endif

  if (NeoUpdate) {
    for (int i=0; i<NUMPIXELS; i++) {pixels.setPixelColor(i, pixels.Color(NeoColors[i*3], NeoColors[i*3+1], NeoColors[i*3+2]));}
    pixels.show();
    NeoUpdate = false;
  }

  digitalWrite(PowerSwitchPin, ControlRegisters[0x03]);
}


void ptc_event_callback(const ptc_cb_event_t eventType, cap_sensor_t* node) {
  #ifdef DEBUG_SERIAL
  if (PTC_CB_EVENT_TOUCH_DETECT == eventType) {
    Serial.print("node touched:");
    Serial.println(ptc_get_node_id(node));
  } else if (PTC_CB_EVENT_TOUCH_RELEASE == eventType) {
    Serial.print("node released:");
    Serial.println(ptc_get_node_id(node));
  } else if (PTC_CB_EVENT_CONV_MUTUAL_CMPL == eventType) {
    // Do more complex things here
  } else if (PTC_CB_EVENT_CONV_CALIB & eventType) {
    if (PTC_CB_EVENT_ERR_CALIB_LOW == eventType) {
      Serial.print("Calib error, Cc too low.");
    } else if (PTC_CB_EVENT_ERR_CALIB_HIGH == eventType) {
      Serial.print("Calib error, Cc too high.");
    } else if (PTC_CB_EVENT_ERR_CALIB_TO == eventType) {
      Serial.print("Calib error, calculation timeout.");
    } else {
      Serial.print("Calib Successful.");
    }
    Serial.print(" Node: ");
    Serial.println(ptc_get_node_id(node));
  }
  #endif
}

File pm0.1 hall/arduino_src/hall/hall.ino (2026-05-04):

void README() {
  return;

  /*
  KH-24 I2C Hall-effect (magnetic) keyboard peripheral module
  Part of Shepherd System
  by Sam Kothe (torbers)

  Makes available states, positions, and state-changes of 32 keys over I2C.


  Hardware:
    Microcontroller: ATTINYx16
    Analog Multiplexer: CD4051
    Sensor: SLSS49E
    Output pin tied to GND via 10k resistor.


  I2C Register Map:
    0x00..0x07: Raw 8-bit analog values of ROW A
    0x08..0x0F: ROW B
    0x10..0x17: ROW C
    0x18..0x1F: ROW D

    0x20..0x27: Calibrated values; max = 0xFF, min = 0x00. ROW A
    0x28..0x2F: ROW B
    0x30..0x37: ROW C
    0x38..0x3F: ROW D

    0x40..0x47: Calibration HIGH
    0x48..0x4F: ROW B
    0x50..0x57: ROW C
    0x58..0x5F: ROW D

    0x60..0x67: Calibration LOW
    0x68..0x6F: ROW B
    0x70..0x77: ROW C
    0x78..0x7F: ROW D


    11: FULLY PRESSED
    10: PARTIALLY PRESSED AFTER FULLY PRESSED
    01: PARTIALLY PRESSED AFTER UNPRESSED
    00: UNPRESSED

    0x80..0x87: Keys according to above chart (rows A, B, C, and D)
    0x88..0x8F: /
    0x90..0x97: /
    0x97..0x9F: /

    0xA0: Positions of keys when last polled by state change request (0xC0) ROW A
    0xA8: ROW B
    0xB0: ROW C
    0xB8: ROW D

    0xC0..0xC7......0xDF: State change keys

    1[0x7 KEY NUMBER]
    00[0x2 OLD STATE]00[0x2 NEW STATE]
    [0x8 CALIBRATED POSITION]
    [0x8 PREVIOUS POSITION]
    Repeat for each new state change
    ....
    Last byte 0b00000000

    Positions copied to 0xA0..0xB8 and register wiped to 0b00000000 immediately after read


  I2C Address Allocation

    Controller routine (each ~200ms)
      Controller sends test address (0x09 for example)
        0x08 WRITE 0xFF 0x01 0x09 STOP
      
      Controller tests address
        0x09
        WRITE
        0xFF (switch to control register)
        0x00 (pointer = 0x00)
        0x00 (write 0x00)
        0x09 (write expected address)
      
      Controller sets pointer
        0x09 WRITE 0xFF (switch to control register)
      
      Controller requests 2 bytes
        0x00 0x09
      
      Recieves 0x09 as expected
    
    Device startup
      Begin Wire on 0x08
      Recieve message from controller
      Switch to assigned address
      Enable power on next device


  Control register:
  0x00 0x00
  0x01 I2C Address
  0x02 0x01 (Module codename)
  0x03 Enable power = 0x01

  0x04 Enable high calibration (all keys) = 0x01
  0x05 Enable low calibration = 0x01
  0x06 Key to calibrate
  0x07 Calibration status : 0x00 = Not calibrating, 0x01 = Calibrating

  0x08..0xA LED color
  */
}

#include <Wire.h>
#include <EEPROM.h>
#include <tinyNeoPixel.h>

//#define DEBUG_SERIAL
//#define WIRE_DEBUG

#define SELA 11
#define SELB 12
#define SELC 13

#define RA 0
#define RB 1
#define RC 2
#define RD 3

#define PowerSwitchPin 4
#define CalibrationEnablePin 15
#define NEOPIXEL_PIN 5

#define DEVICE_ADDR 0x69
#define REGISTER_SIZE 0xFF
#define C_REGISTER_SIZE 0x0F

#define THRESH_HIGH 240
#define THRESH_LOW  50

#define NUMPIXELS 1

// MIDI message types
#define KEY_ON       0x80;
#define KEY_OFF      0x90;
#define AFTERTOUCH   0xA0;

// Codes from changes register
#define FULLY_PRESSED             0b11
#define PARTIAL_AFTER_FULL        0b10
#define PARTIAL_AFTER_UNPRESSED   0b01
#define UNPRESSED                 0b00

// Assigning numbers to modules' codenames in Shepherd System
#define KT05   0x00 // This control module
#define KH24   0x01 // 24-key hall keyboard
#define KC02   0x02 // 2-channel pitch bend/mod/cc controller

int hallValue;
unsigned long us;
unsigned long nus;

uint16_t allValuesNowA[7];
uint16_t allValuesNowB[7];
uint16_t allValuesNowC[7];
uint16_t allValuesNowD[7];

volatile uint8_t DeviceRegisters[REGISTER_SIZE];
volatile uint8_t ControlRegisters[C_REGISTER_SIZE];
volatile uint8_t WirePointer = 0;

volatile uint8_t NewAddress = 0x00;
volatile uint8_t af = 0x00;

bool NeoUpdate = false;
uint8_t NeoColors[3];


tinyNeoPixel pixels = tinyNeoPixel(NUMPIXELS, NEOPIXEL_PIN, NEO_GRB + NEO_KHZ800);


// I2C Functions

uint8_t startupAddressAlloc(){
  Wire.begin(0x08);
  Serial.println("Wire started on 0x08");
  Wire.onReceive(startupWireHandler);
  Serial.println("Handler set");
  while (!af) {Serial.println(millis()); delay(10);}
  Serial.println(NewAddress);
  
  return NewAddress;
}


void startupWireHandler(int nb) {
  if (Wire.read() == 0xFF) { 
    #ifdef WIRE_DEBUG
      Serial.println("Recieved 0xFF");
    #endif
    if (Wire.read() == 0x01) {
      #ifdef WIRE_DEBUG
        Serial.println("Recieved 0x01");
      #endif
      NewAddress = Wire.read();
      #ifdef WIRE_DEBUG
        Serial.print("Recieved new addr: 0d");
        Serial.println(NewAddress);
      #endif
      delay(1);
      #ifdef WIRE_DEBUG
        Serial.println("Writing 0xd");
      #endif
      Wire.write(0x00); 
      #ifdef WIRE_DEBUG
        Serial.print("Writing 0d");
        Serial.println(NewAddress);
      #endif
      Wire.write(NewAddress);
      delay(10);
      af = 1;
    }
  }
}


void receiveHandler(int numbytes){
  // Handle writes to registers from I2C controller
  // Modified by me from original by SpenceKonde
  uint8_t ReadData;
  Wire.getBytesRead();
  WirePointer = Wire.read();

  #ifdef WIRE_DEBUG
    Serial.println();
    Serial.println("Recieve handler");

    Serial.println(millis());
    Serial.print("Pointer: 0d");
    Serial.println(WirePointer);
  #endif

  if (WirePointer == 0xFF) {
      #ifdef WIRE_DEBUG
        Serial.println("Control register selected");
      #endif

      numbytes--;
      if (Wire.available()){
        WirePointer = Wire.read();
      }
      else {return;}

      #ifdef WIRE_DEBUG
        Serial.print("Ctl addr: 0d");
        Serial.println(WirePointer);
      #endif

      numbytes--;
      while (numbytes > 0) {
        ReadData = Wire.read();
        #ifdef WIRE_DEBUG
          Serial.print("Recieved into register: 0d"); Serial.println(ReadData);
        #endif
        ControlRegisters[WirePointer] = ReadData;
        if (WirePointer >= 0x08) {NeoColors[WirePointer - 0x08] = ReadData; NeoUpdate = true;}
        WirePointer++;
        numbytes--;
    }
    return;
  }

  numbytes--;
    while (numbytes > 0) {
      ReadData = Wire.read();
      DeviceRegisters[WirePointer] = ReadData;
      WirePointer++;
      numbytes--;
    }
}
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

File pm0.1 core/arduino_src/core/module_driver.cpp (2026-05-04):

#include "module_driver.h"

ModuleDriver::ModuleDriver(CoreWireDriver& wire_driver_arg, MidiMgmt& midi_mgmt, CoreScreen& screen_arg) {
  WireDriver = &wire_driver_arg;
  midi = &midi_mgmt;
  screen = &screen_arg;
}

//#define UPDATE_DEBUG

uint8_t ModuleDriver::updateModules() {
  #ifdef UPDATE_DEBUG
  Serial.println("Updating modules...");
  Serial.println(WireDriver->Chain[1]->codename);
  Serial.println("ok...");
  #endif
  
  
  for (uint8_t m = 0; (WireDriver->Chain[m]->codename != 0xFF) || m>MAX_MODULE_COUNT; m++) {

    #ifdef UPDATE_DEBUG
    Serial.println(m);
    #endif

    WireDriver->Chain[m]->MicrosSinceLastRead = micros() - WireDriver->Chain[m]->MicrosAtLastRead;
    WireDriver->Chain[m]->MicrosAtLastRead = micros();
    uint8_t addr = WireDriver->Chain[m]->address;

    if (WireDriver->Chain[m]->newm) {
      Serial.println("New module...");
      WireDriver->Chain[m]->newm = false;
      Serial.println("New module...");
      switch (WireDriver->Chain[m]->codename) {
        case HALL:
          Serial.println("routine...");
          doBottomOutCalibrationRoutine(addr);
          break;
        case MODS:
          break;
        default:
          return 0x00;
      }
    }

    switch (WireDriver->Chain[m]->codename) {
      case HALL:
        updateHall(WireDriver->Chain[m]);
        break;
      case MODS:
        break;
      default:
        return 0x00;
    }
  }
  return 0x01;
}


// functions for HALL

uint8_t ModuleDriver::updateHallDebug(Module* hall) {
  //delay(500);
  screen->tft.fillScreen(0x07E0);
  screen->tft.setCursor(0, 0);


  static uint8_t all_reg[0xFF];


  for(uint8_t p = 0; p<8; p++){
    screen->tft.print(p);

    WireDriver->Wire->beginTransmission(hall->address);
    WireDriver->Wire->write(0x20 * p);
    WireDriver->Wire->endTransmission();

    WireDriver->Wire->requestFrom(hall->address, 0x20);

    uint8_t kn = 0;
    while (WireDriver->Wire->available()) {
      all_reg[0x20 * p + kn] = WireDriver->Wire->read();
      kn++;
    }

  Serial.println();
  }



  static uint8_t changes_register[CHANGES_LENGTH];

  for (int i = 0; i<CHANGES_LENGTH; i++){changes_register[i] = all_reg[i+0xC0];}

  uint8_t ch = hall->PositionInChain;
  
  
  unsigned long dt = hall->MicrosSinceLastRead;
  Serial.println(dt);

  screen->tft.println("values:");

  screen->tft.println("a values:");
  for (uint8_t v = 0; v < 0x04; v++) {screen->tft.print(all_reg[v], HEX);}
  screen->tft.println();
  screen->tft.println("calib:");
  for (uint8_t v = 0x20; v < 0x24; v++) {screen->tft.print(all_reg[v], HEX);}
  screen->tft.println();
  screen->tft.println("hi:");
  for (uint8_t v = 0x40; v < 0x44; v++) {screen->tft.print(all_reg[v], HEX);}
  screen->tft.println();
  screen->tft.println("low:");
  for (uint8_t v = 0x60; v < 0x64; v++) {screen->tft.print(all_reg[v], HEX);}
  screen->tft.println();
  screen->tft.println("c:");
  for (uint8_t v = 0xC0; v < 0xC8; v++) {screen->tft.print(all_reg[v], HEX);}
  screen->tft.println();


  for (uint8_t i = 0; i < (CHANGES_LENGTH >> 2); i++){
    
    if (changes_register[i*4] == 0x00) {screen->tft.println("if"); break;}
    screen->tft.println("cr");

    uint8_t key_number = changes_register[i*4] - 0x80;

    uint8_t old_state = changes_register[i*4+1] >> 4;

    uint8_t new_state = changes_register[i*4+1] - (old_state << 4);

    uint8_t new_position = changes_register[i*4+2] - 0x80;

    uint8_t old_position = changes_register[i*4+3] - 0x80;

    uint8_t true_key = sortKeys(key_number);
    
    if (true_key == 0xFF) {return 0xFF;}

    if (new_state == 0b11) {midi->sendMidiDataUSB(0x90, ch, true_key, 0x7F);}
    if (new_state == 0b00) {midi->sendMidiDataUSB(0x80, ch, true_key, 0x00);}
    
    
  }

  return 0x00;
}


uint8_t ModuleDriver::updateHall(Module* hall) {
  //delay(500);
  //screen->tft.fillScreen(0x07E0);
  //screen->tft.setCursor(0, 0);


  static uint8_t changes_register[CHANGES_LENGTH];



  WireDriver->Wire->beginTransmission(hall->address);
  WireDriver->Wire->write(0xC0);
  WireDriver->Wire->endTransmission();

  WireDriver->Wire->requestFrom(hall->address, 0x20);

  uint8_t kn = 0;
  while (WireDriver->Wire->available()) {
    changes_register[kn] = WireDriver->Wire->read();
    kn++;
  }


  uint8_t ch = hall->PositionInChain;
  
  
  unsigned long dt = hall->MicrosSinceLastRead;
  //Serial.println(dt);


  for (uint8_t i = 0; i < (CHANGES_LENGTH >> 2); i++){
    
    if (changes_register[i*4] == 0x00) {break;}//screen->tft.println("if"); break;}
    //screen->tft.println("cr");

    uint8_t key_number = changes_register[i*4] - 0x80;

    uint8_t old_state = changes_register[i*4+1] >> 4;

    uint8_t new_state = changes_register[i*4+1] - (old_state << 4);

    uint8_t new_position = changes_register[i*4+2] - 0x80;

    uint8_t old_position = changes_register[i*4+3] - 0x80;

    uint8_t true_key = sortKeys(key_number);
    
    if (true_key == 0xFF) {return 0xFF;}
    //uint8_t tv = 127 - constrain(new_position - 127, 0, 127);


    //if (old_state == 0b00 and (new_state == 0b01 or new_state == 0b10 or new_state == 0b11) ) {midi->sendMidiDataUSB(0x90, ch, true_key, 127);}
    if (new_state = 0b11) {midi->sendMidiDataUSB(0x90, ch, true_key, 127);}
    if (new_state == 0b00) {midi->sendMidiDataUSB(0x80, ch, true_key, 0x00);}
    
    
  }

  return 0x00;
}


/*
uint8_t* ModuleDriver::getChangesHall(uint8_t addr) {
  WireDriver->Wire->beginTransmission(addr);
  WireDriver->Wire->write(0xC0);
  WireDriver->Wire->endTransmission();

  WireDriver->Wire->requestFrom(addr, CHANGES_LENGTH);

  uint8_t *return_reg = (uint8_t*) malloc(CHANGES_LENGTH);
  uint8_t i = 0;
  while (WireDriver->Wire->available()) {
    return_reg[i] = WireDriver->Wire->read();
    Serial.print(return_reg[i], BIN); Serial.print(" ");
    i++;
  }


  Serial.println();

  return return_reg;
}

uint8_t* ModuleDriver::getValuesHall(uint8_t addr) {
  WireDriver->Wire->beginTransmission(addr);
  WireDriver->Wire->write(0x00);
  WireDriver->Wire->endTransmission();

  WireDriver->Wire->requestFrom(addr, 0x20);

  uint8_t return_reg[0x20];
  uint8_t i = 0;
  uint8_t kn = 0;
  while (WireDriver->Wire->available()) {
    if (true){//!((i == 0) || (i == 4) || (i == 7) || (i == 7) || (i == 15) || (i == 16) || (i == 20) || (i == 23) || (i==31)) ) {
      return_reg[kn] = WireDriver->Wire->read();
      Serial.print(return_reg[kn], HEX); Serial.print(" ");
      kn++;
    }
    else {WireDriver->Wire->read();}

    i++;
  }

  Serial.println();

  return return_reg;
}
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

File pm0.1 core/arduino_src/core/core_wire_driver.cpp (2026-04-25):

#include "core_wire_driver.h"

CoreWireDriver::CoreWireDriver(TwoWire& wire_arg, MidiMgmt& midi_arg) {
  ModuleCount = 0;
  Wire = &wire_arg;
  MidiCall = &midi_arg;
  Module NullModule;
  for (uint8_t i = 0; i<MAX_MODULE_COUNT; i++) {Chain[i] = &NullModule;}
}

bool CoreWireDriver::begin(uint8_t wire_sda, uint8_t wire_scl, uint32_t wire_clock) {
  Wire->setClock(wire_clock);
  return Wire->begin(wire_sda, wire_scl);
}

uint8_t CoreWireDriver::setControlRegVariable(uint8_t address, uint8_t register_address, uint8_t new_value) {
  Wire->beginTransmission(address);
  Wire->write(0xFF);
  Wire->write(register_address);
  Wire->write(new_value);
  Wire->endTransmission();

  Wire->requestFrom(address, 1);
  if (Wire->available()) {return Wire->read();}
  return 0x00;
}

uint8_t CoreWireDriver::findNextNewModule() {
  Serial.print("Beginning on 0d");
  Serial.println(BeginningAddress);

  setControlRegVariable(BeginningAddress, 0x01, NextNewAddress);


  Serial.print("Testing 0d");
  Serial.println(NextNewAddress);


  Wire->beginTransmission(NextNewAddress);
  Wire->write(0xFF);
  Wire->write(0x00);
  Wire->write(0x00);
  Wire->write(NextNewAddress);
  Wire->endTransmission();


  Wire->beginTransmission(NextNewAddress);
  Wire->write(0xFF);
  Wire->endTransmission();

  delay(5);

  uint8_t recieved_addr = 0x00;
  uint8_t recieved_type;

  Wire->requestFrom(NextNewAddress, 3);


  if (Wire->available()) {
    Serial.println("W avail...");
    uint8_t wr = Wire->read();
    Serial.println(wr);

    if (wr == 0x00) {
      Serial.println("Recieved 0x00");
      recieved_addr = Wire->read();
      Serial.print("Recieved addr 0d");
      Serial.println(recieved_addr);

      recieved_type = Wire->read();
      Serial.print("Type: "); Serial.println(recieved_type);
    }
  }

  Serial.print("recieved_addr: "); Serial.println(recieved_addr);
  Serial.print("NextNewAddress: "); Serial.println(NextNewAddress);

  if (recieved_addr == NextNewAddress) {
    // connection confirmed - create module
    Serial.print("Creating module at "); Serial.println(recieved_addr);

    uint8_t module_type = recieved_type;

    Serial.print("module_type: "); Serial.println(module_type);

    switch (module_type) {
      case HALL:
        Chain[ModuleCount] = new Hall(NextNewAddress);
        Chain[ModuleCount]->PositionInChain = ModuleCount;

        setControlRegVariable(Chain[ModuleCount]->address, 0x04, 0x01);
        setControlRegVariable(Chain[ModuleCount]->address, 0x08, 0x00);

        Serial.println("HALL");
        break;

      case MODS:
        Chain[ModuleCount] = new Mods(NextNewAddress);
        Chain[ModuleCount]->PositionInChain = ModuleCount;
        Serial.println("MODS");
        break;

      default:
        Serial.println("NULL");
        return 0x00;
    }

    ModuleCount++;

    NextNewAddress++;
    Serial.println(NextNewAddress - 1);
    Serial.println("NEW MODULE ADDED");
    return NextNewAddress - 1;
  }
  else {Serial.println("NEW MODULE NOT ADDED"); return 0x00;}
}

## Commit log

2025-12-22 added alpha src files & prototype files
    [bendmod.kicad_pcb, bendmod.kicad_sch, bom.csv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]
2025-12-25 device discovery works
2025-12-31 beginning to create module chains
2026-01-15 added version 1.0 of kicad file for kh-24
    some eva inspired posters too, have fun
    [bom.csv, designators.csv, kh-24.kicad_sch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]
2026-01-15 created km-02 modwheels
    [km-05.kicad_pcb, km-05.kicad_sch]
2026-01-18 km-5 mostly finished
    [kh-24.kicad_sch, km-05.kicad_pcb, km-05.kicad_sch]
2026-02-15 core mainboard
    [km-05.kicad_pcb, km-05.kicad_sch, kt-05.kicad_pcb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]
2026-02-25 improved fuses
    [core_faceplate.kicad_pcb, kt-05.kicad_pcb, kt-05.kicad_sch]
2026-02-27 hall faceplate
    [core_faceplate.kicad_pcb, hall face.kicad_pcb, hall face.kicad_sch]
2026-03-01 faceplate designs
    [core_faceplate.kicad_pcb, hall face-F_Silkscreen.dxf, km-05_faceplate.kicad_pcb]
2026-03-21 production 1
    [bom.csv, core_faceplate.kicad_pcb, core_faceplate.step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]
